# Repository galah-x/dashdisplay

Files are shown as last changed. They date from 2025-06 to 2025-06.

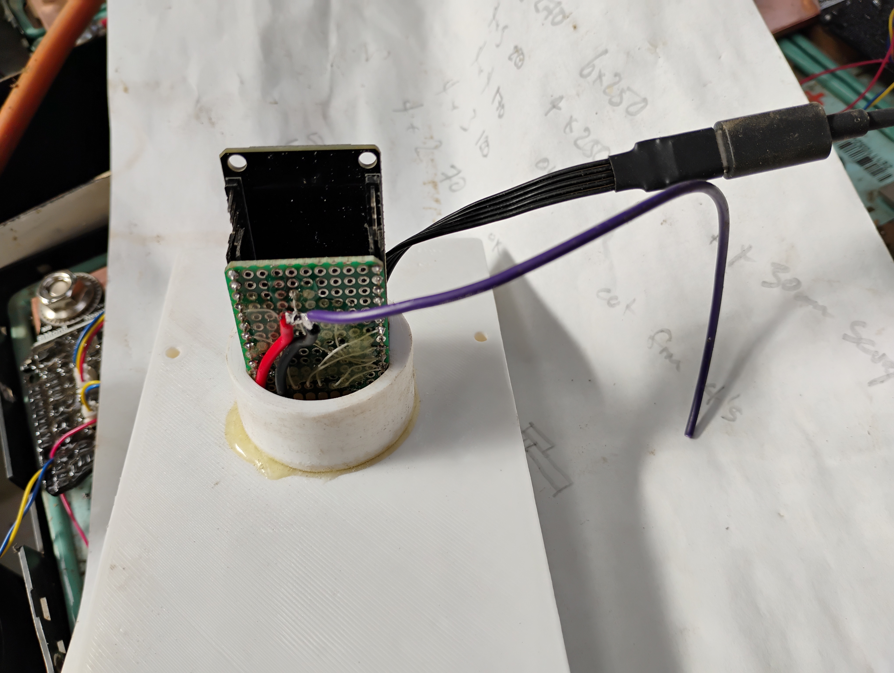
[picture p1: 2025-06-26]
pics/13_assembly_order.jpg

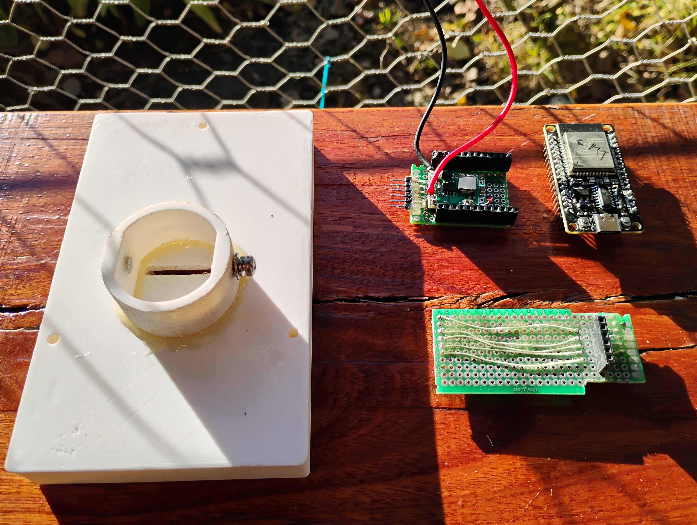
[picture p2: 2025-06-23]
pics/04_components_glued.jpg

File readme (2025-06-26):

Readme for Dashdisplay.
John Sheahan June 2025

This thing is a dashboard display for an Electric Haflinger I'm building. I want to be able to monitor battery voltage, current and StateOfCharge. I also wanted to see the range of individual cell voltages and cell temperatures.

All of this information is available to the BMS, and the Batrium BMS I have thoughtfully broadcasts the relevant information using UDP on its internal wireleass AP. Batrium is even civilized enough to document and publish the detail on their wiki.

So its pretty easy to build a display with an ESP32 and some Sharp sunlight readable sort-of-LCDs from Adafruit to display the desired information on the dashboard with no wiring except 12V power.

The code needs an Arduino setup with ESP32 support loaded.   Its the .h and .ino files. And a few standard add-in libraries the compiler will flag.

Programming the ESP32 board is done with a usb-C cable from the arduino UI.

Use the arduino serial monitor to program your WiFI AP SSID and password. Serial runs at 115200 baud.  I discovered the Batrium SSID with my phone searching for WiFi. The Batrium password is pin123456, replace 123456 with the pinnumber written on the back of the WatchMon.

I wrote a test script test_app/udp_tester.pl you can use to test the dispay if you build one, without actually needing a Batrium setup and/or being close to it.

The dashdisplay has the following hardware components:
  * a 3d printed front frame to hold the 2 LCDs and a wiring board for them.
  * a clear acrylic front plate
  * 2 adafruit sharp lcd displays. 400x240 pixels. Add a 6 pin machine screw pin header to each.
  * a wiring board. I used a scrap of FR4 protoboard with 2 6 pin machine screw socket strips and a 6 pin socket strip on the back. The 2 displays Vin, gnd, spi_clk, spi_mosi are in paralell. The 2 CS pins are brought out separately.
  * the round spigot on the back of the front frame goes through a hole in the dash

Then the is some electronics:
  * a 'motherboard' with socket strip pins to hold an ESP32 module.
  * motherboard has 6 pins of 0.1 inch pinstrip at the front
  * motherboard has a small 12V to 5V switching module on it also, aliexpress
  * motherboard has 10 wires on the back
  * esp32 wroom 32 module from aliexpress.
  * optional flexible right angle USBC cable to alow reprogramming. Mine came from Aliexpress.

Then there is a 3d printed back assembly. It goes over the spigot on the front assembly . The electronics goes inside. There is a spot for a XT60 flanged connector for 12V. And a hole to let the USBC cable out. Probably should silicone up the cable hole once the cable is fitted.

Both 3D printed part needs supports. Cleaning out the support was tedious. They should probably be designed the other way up (a change to the front spigot would be needed).  Feel free to do that better. Freecad design (I used version 1.0.1) stl files and gcode are in the repo. 

There are schematics of the mother and display wiring boards  in teh schematics directory.
There are a few pictures of the bits and the assembly, with the display working against the batrium  WatchMon , in the
pics directory.

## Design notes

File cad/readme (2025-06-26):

Some of the files here, and their issues.:

dd_3.FCStd
Is the original front , with a spigot.
It prints from the outside front face down.
I printed it with supports, so it takes quite a while to clean up.
Its generally too tight on the display in XY and tight on the display wiring board in Z. 
Worked for SW dev.

 - Currently these three parts are used.
 - about 7 hrs to print dd_front_nospigot.FCStd, 1 hr for the spigot, 4 hrs for dd3_back2.FCStd
   - on the mighty Creality ender3v2 that is. In PLA.

dd3_back2.FCStd
This is the original and so far only surround around the esp32. It goes over the spigot.
It prints spigot side down. This needed vigourous sanding with a dremel sandpaper drum to remove supports.
Otherwise it seems OK.
If I needed another one I'd redraw it with a taper around the waist so it prints in reverse (ie solid back on the bed) with no supports. 

dd_front_nospigot.FCStd
This is a redraw of dd_3.FCStd to add 0.5mm all around the display, and an extra mm of Z for both
display and wiring board.  Its designed to print with the rear (surface on dash) on the bed. No supports needed.
No spigot, just a groove to locate the spigot while its epoxied in. 
I also changed to heat formed stakes to hold down the display, which was a mistake. They missed position by a
few tenths of a mm,  and were too fragile to shave down. I just broke them off and will fit either self tappers or maybe a bit of filament to hold the displays in. Self tappers are on order. I pushed in some 2.5mm heat set threaded inserts. As I didn't have holes with walls, was a little ordinary, but worked.
Note I had to ease the slot for the connector in the front.

dd_spigot.FCStd
The same spigot design used in the first one, without the front, and a pointy end to match the groove in dd_front_nospigot.FCStd

Note assembly is a bit tricky. See the pictures.
Glue in the spigot.
Ease the slot for the 0.1 inch pinstrip in the front piece with a file.
Fit the display wiring board.
Fit flexible right angle USB cable to the ESP32. This will allow reprogramming later without disassembly.
fit 12v wires. Leave then long.
Fit motherboard into the connecter for the display board.
Mount front board through dash
feed the USB and 12V leads through the back printed part.
push the back cover on, bringing the leads out.
Solder the 2 12V wires to the XP60 connector, as short as practical.
screw in the xp60
screw in the back
plug in and screw in the 2 displays from the front.

Thats all a bit messy.

Changes I should make:

Front
  * displays should be held in with screws or nutserts, not thermal posts. Also the exact placement of the posts is wrong by a few tenths of a mm.  the posts dont have a hole with walls nder for either nutserts or self tappers.
  * the slot for the female pin strip is too narrow. Display to motherboard connector.  Needs filing currently.

Spigot
  * cheeks for the 4mm nutserts are a bit small. Reduce to 3mm?

Back
  * prints backwards. want to do flat back on the printer bed. Far too much cleanup curently. Maybe a taper to the shoulder.
  * Assembly is difficult. I'd prefer to be able to assemble without removing the XP60. Have to bend the flex USB cable too.
    * Could I add an extra small connector in the 12V so the XP60 plugs in?
      * as I need to plug the MB into display board, then feed wires into the holes in the back, while sliding back over spigot, would be a long wire to locate somewhere.  Right now I use a single feeder wire soldered to both red and black ends to pull through, prior to unsoldering feeder then soldering on XP60. 
    * Could I do a slot so the wires fit between spigot and back?
    * XP60 on the back of the front part? (not nice).
    * perhaps the 12V to 5V switcher should be on a bulge on the side of the back, so that USB is the only cable?
    * or even usb to a separate blob nearly, with 12V on one side and usbC on the other. Unplug the USB for programming. Keep it flat to the display so as to not shroud the wifi antenna of the wsp32 module. 
  * Hopefully doesn't have to come apart often.

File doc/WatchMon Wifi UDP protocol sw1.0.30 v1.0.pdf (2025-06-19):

Watchmon SW 1.0.30 UDP Outbound protocol

## WatchMon - Wifi UDP protocol

Version
1.0 – 1/12/2017 – Software 1.0.30

Communication Overview
Outbound messages are broadcast to
Supervisor broadcasts to udp port 18542 at IP 255.255255.255

Payload format
- | Pos 0 | “:” Start Header character colin (0x3A)
- Pos 1..2 UInt16 MessageType
- | Pos 3 | “,” seperator comma
- Pos 4 uint16 SystemID
- Pos 6 uint16 HubID (default 0 - future extension of SystemID )

Wifi Broadcast modes
- Idle – no broadcast communication
- Limited - Only send Discover MsgType every 1.5 Seconds
- Verbose (default) - All messages scheduled in their relevate frequency slot transmitted at ~50mS interval
- Verbose (read only)
- Disabled - module powered down

## Outbound messages Types

Frequency A - 150 millisecond
- 0x415A – Individual cell monitor Basic Status (subset for up to 16)
- 0x4232 – Individual cell monitor Full Info (node specific)

Frequency B - 300 milliseconds
- 0X3E32 – Telemetry - Combined Status Rapid Info

Frequency C - 1.5 seconds
- 0X3F33 – Telemetry - Combined Status Fast Info
- 0X4732 – Telemetry - Logic Control Status Info
- 0x4932 – Telemetry - Remote Status Info
- 0x6131 – Telemetry - Communication Status Info
- 0x5732 – System Discovery Info

Frequency D - 22 seconds
- 0X4032 – Telemetry - Combined Status Slow Info
- 0x5432 – Telemetry - Daily Session Info
- 0x7857 – Telemetry - Shunt Metric Info
- 0x5632 – Telemetry - Life Metric Info
- 0X4A35 – Hardware - System setup configuration Info
- 0X4B35 – Hardware - Cell Group setup configuration Info
- 0X4C33 – Hardware - Shunt setup configuration Info
- 0X4D33 – Hardware - Expansion setup configuration Info
- 0X5334 – Hardware - Integration setup configuration Info
- 0X4F33 – Control logic – Critical setup configuration Info
- 0X5033 – Control logic - Charge setup configuration Info
- 0X5158 – Control logic - Discharge setup configuration Info
- 0X5258 – Control logic - Thermal setup configuration Info
- 0X4E58 – Control logic - Remote setup configuration Info

Frequency E - Adhoc request / response
- 0x5831 – Telemetry - Daily Session History
- 0x6831 – Telemetry - Quick Session History
- 0x5431 – Telemetry - Session Metrics

## System Discovery Information – payload formatting

Identifier: 0X5732 Recommended to monitor
Frequency: 1.55 seconds
Data Length: 50 bytes
Version 2
Field | Offset | Data Type | Format / Range | Resolution / Notes
System Code | 8 | Text 8
Firmware Version | 16 | Uint16
Hardware Version | 18 | Uint16
Device Time | 20 | Uint32 | Unix Epoch | seconds since 1-1-1970
System Op status | 24 | Uint8 | Timeout = 0, Idle = 1, // LED = green slow pulse Charging = 2, // LED = blue slow pulse Discharging = 3, // LED = green solid Full = 4, // LED = blue double blink Empty = 5, // LED = green double blink Simulator = 6 , // LED = rainbow pulse CriticalPending = 7, // LED = red fast pulse CriticalOffline = 8, // LED = red slow pulse MqttOffline = 9, // LED = white blink AuthSetup = 10, // LED = white solid
System Auth Mode | 25 | Uint8 | 0 = Default 1 = Technician 2 = Factory
Critical BattOkState | 26 | Bool | 0 or 1
Charge PowerRate State | 27 | Uint8 | Off = 0, Limited = 2, Normal = 4,
Discharge PowerRate State | 28 | Uint8
Heat On State | 29 | Bool | 0 or 1
Cool On State | 30 | Bool | 0 or 1
Min Cell Volt | 31 | Uint16 | 0 to 6,500 mV | 1mV / bit and nil offset
Max Cell Volt | 33 | Uint16 | 0 to 6,500 mV | 1mV / bit and nil offset
Avg Cell Volt | 35 | Uint16 | 0 to 6,500 mV | 1mV / bit and nil offset
Min Cell Temp | 37 | Uint8 | -40ºC to 125ºC | 1ºC/bit and 40ºC offset
Num of active Cellmons | 38 | Uint8 | 0 to 254
CMU Port Rx USN | 39 | Uint8
CMU Poller Mode | 40 | Uint8 | Idle = 0, Normal = 1, Start collection = 2, Collection running = 3, Start syncronisation = 4, Sync Running = 5, Start NetworkTest = 6, NetworkTest running = 9, Start BypassTest = 7, BypassTest running = 8, Start Reboot All = 10, Reboot All devices = 11, Start Simulator = 12, Simulator running = 13, Undefined = 255,

Cont../

Shunt SoC | 41 | uint8 | -5% to +105% | 0.5% / bit and 5% offset
Shunt Voltage | 42 | Uint16 | | Multiple (100) according to setup
Shunt Current | 44 | Float | mA | (+ charge , - discharge)
Shunt Status | 48 | Uint8 | Timeout = 0, Discharging = 1, Idle = 2, Charging = 4
Shunt RX ticks | 49 | Uint8

## Telemetry - Combined Status Rapid Info – payload formatting

Identifier: 0x3E32 – Recommended to monitor
Frequency: 294 milliseconds
Data Length: 50 bytes
Version 2
Field | Offset | Data Type | Format / Range | Resolution / Notes
Min Cell Voltage | 8 | Uint16 | 0 to 6,500 mV | 1mV / bit and nil offset
Max Cell Voltage | 10 | Uint16 | 0 to 6,500 mV | 1mV / bit and nil offset
Min Cell Volt Reference | 12 | Uint8 | 0 to 250 | Node Identifier
Max Cell Volt Reference | 13 | Uint8 | 0 to 250 | Node Identifier
Min Cell Temperature | 14 | uint8 | -40ºC to 125ºC | 1ºC/bit and 40ºC offset
Min Cell Temperature | 15 | uint8 | -40ºC to 125ºC | 1ºC/bit and 40ºC offset
Min Cell Temp Reference | 16 | Uint8 | 0 to 250 | Node Identifier
Max Cell Temp Reference | 17 | Uint8 | 0 to 250 | Node Identifier
Min Cell Bypass Current | 18 | Uint16 | 0 to 2,500 mA | 1mA / bit and nil offset
Max Cell Bypass Current | 20 | Uint16 | 0 to 2,500 mA | 1mA / bit and nil offset
Min Cell Bypass Ref ID | 22 | Uint8 | 0 to 250 | Node Identifier
Max Cell Bypass Ref ID | 23 | Uint8 | 0 to 250 | Node Identifier
Min Bypass Temperature | 24 | uint8 | -40ºC to 125ºC | 1ºC/bit and 40ºC offset
Min Bypass Temperature | 25 | uint8 | -40ºC to 125ºC | 1ºC/bit and 40ºC offset
Min Bypass Temp Ref ID | 26 | Uint8 | 0 to 250 | Node Identifier
Max Bypass Temp Ref ID | 27 | Uint8 | 0 to 250 | Node Identifier
Average Cell Voltage | 28 | Uint16 | 0 to 6,500 mV | 1mV / bit and nil offset
Average Cell Temperature | 30 | uint8 | -40ºC to 125ºC | 1ºC/bit and 40ºC offset
Num# of Cells Above Initial Bypass | 31 | Uint8 | 0 to 250
Num# of Cells Above Final Bypass | 32 | Uint8 | 0 to 250
Num# of Cells in Bypass | 33 | Uint8 | 0 to 250
Num# of Cells Overdue | 34 | Uint8 | 0 to 250
Num# of Cells Active | 35 | Uint8 | 0 to 250
Num# of Cells in System | 36 | Uint8 | 0 to 250
CMU port TX NodeID | 37 | Uint8
CMU port RX NodeID | 38 | Uint8
CMU port RX USN | 39 | Uint8 | 0 to 254 | Serial number packet counter
Shunt Voltage | 40 | Uint16 | | Multiple (100) according to setup
Shunt Amp | 42 | Float | mA | (+ charge , - discharge)
Shunt Power | 46 | Float | VA | (+ charge , - discharge)

## Telemetry - Combined Status Fast Info – payload formatting

Identifier: 0X3F33 – Recommended to monitor
Frequency: 1.55 seconds
Version: 3
Data Length: 80 bytes
Field | Offset | Data Type | Format / Range | Resolution / Notes
CMU Poller Mode | 8 | Uint8 | 0 = Idle, 1 = Normal, 2 = Start collection, 3= Collection running, 4 = Start synchronisation, 5 = Sync Running, 6 = Start NetworkTest, 9 = NetworkTest running, 7 = Start BypassTest, 8 = BypassTest running, 10 = Start Reboot All, 11 = Reboot All devices, 12 = Start Simulator, 13 = Simulator running,
CMU Port TX Ack count | 9 | Uint8 | 0 to 250
CMU Port TX Op Status NodeID | 10 | Uint8 | | Node Identifier
CMU Port TX Op Status USN | 11 | Uint8 | 0 to 254 | Serial packet counter
CMU Port TX Op Parameter NodeID | 12 | uint8 | | Node Identifier
Group Min Cell Volt | 13 | Uint16 | 0 to 6,500 mV | 1mV / bit and nil offset
Group Max Cell Volt | 15 | Uint16 | 0 to 6,500 mV | 1mV / bit and nil offset
Group Min Cell Temp | 17 | Uint8 | -40ºC to 125ºC | 1ºC/bit and 40ºC offset
Group Max Cell Temp | 18 | Uint8 | -40ºC to 125ºC | 1ºC/bit and 40ºC offset
CMU Port RX Op Status NodeID | 19 | Uint8 | 0 to 250 | Node Identifier
CMU Port RX Op Status Group Acknowledgement | 20 | Uint8
CMU Port RX Op Status USN | 21 | Uint8 | 0 to 254 | Serial packet counter
CMU Port RX Op Parameter NodeID | 22 | Uint8 | 0 to 250 | Node Identifier
System Op status | 23 | Uint8 | Timeout = 0, Idle = 1, // LED = green slow pulse Charging = 2, // LED = blue slow pulse Discharging = 3, // LED = green solid Full = 4, // LED = blue double blink Empty = 5, // LED = green double blink Simulator = 6 , // LED = rainbow pulse CriticalPending = 7, // LED = red fast pulse CriticalOffline = 8, // LED = red slow pulse MqttOffline = 9, // LED = white blink AuthSetup = 10, // LED = white solid
System Auth Mode | 24 | Uint8 | 0 = Default 1 = Technician 2 = Factory
System Supply Volt | 25 | Uint16 | 0 to 6,500 mV | 1mV / bit and nil offset
System Ambient Temp | 27 | Uint8 | -40ºC to 125ºC | 1ºC/bit and 40ºC offset
System Device Time | 28 | Uint32 | Date Time | 1sec/bit since 1.1.1970
Shunt State of Charge | 32 | Uint8 | -5% to +105% | 0.5% / bit and 5% offset

Shunt Celsius | 33 | Uint8 | -40ºC to 125ºC | 1ºC/bit and 40ºC offset
Shunt Nom. Capacity to full | 34 | Float | mAh
Shunt Nom. Capacity to empty | 38 | Float | mAh
Shunt Poller Mode | 42 | Uint8 | 0 = Start sync, 1 = Sync running, 2 = Normal, 3 = Idle,
Shunt Status | 43 | Uint8 | Timeout = 0, Discharging = 1, Idle = 2, Charging = 4
Shunt Lo State of Charge Re Calibration | 44 | Bool | 0 or 1
Shunt Hi State of Charge Re Calibration | 45 | Bool | 0 or 1
Expansion Output Battery On | 46 | Bool | 0 or 1
Expansion Output Battery Off | 47 | Bool | 0 or 1
Expansion Output Load On | 48 | Bool | 0 or 1
Expansion Output Load Off | 49 | Bool | 0 or 1
Expansion Output Relay 1 | 50 | Bool | 0 or 1
Expansion Output Relay 2 | 51 | Bool | 0 or 1
Expansion Output Relay 3 | 52 | Bool | 0 or 1
Expansion Output Relay 4 | 53 | Bool | 0 or 1
Expansion Output PWM1 | 54 | Uint16
Expansion Output PWM2 | 56 | Uint16
Expansion Input Run LED Mode | 58 | Bool | 0 or 1
Expansion Input Charge Normal Mode | 59 | Bool | 0 or 1
Expansion Input Battery Contactor | 60 | Bool | 0 or 1
Expansion Input Load Contactor | 61 | Bool | 0 or 1
Expansion Input Signal In | 62 | Uint8
Expansion Input AIN1 | 63 | Uint16
Expansion Input AIN2 | 65 | Uint16
Min Bypass Session | 67 | Float | mAh | mAh
Max Bypass Session | 71 | Float | mAh | mAh
Min Bypass Session Reference | 75 | Uint8 | 0 to 250 | Node Identifier for Min
Max Bypass Session Reference | 76 | Uint8 | 0 to 250 | Node Identifier for Max
Rebalance Bypass extra | 77 | Bool | 0 or 1 | When invoked
Repeat Cell Volt Counter | 78 | Uint16 | 0 to 6700 | Num of msg with cell voltage unchanged

## Telemetry - Combined Status Slow Information – payload formatting

Identifier: 0X4032
Frequency: 22 seconds
Data Length: 66 bytes
Version: 2
Field | Offset | Data Type | Format / Range | Resolution / Notes
Sys Start up Time | 8 | Uint32 | Unix Epoch | seconds since 1-1-1970
Sys Process Control | 12 | Bool | 0 or 1
Sys Is Initial Start up | 13 | Bool | 0 or 1
Sys Ignore When Cells Overdue | 14 | Bool | 0 or 1
Sys Ignore When Shunts Overdue | 15 | Bool | 0 or 1
Monitor Daily Session Stats for system | 16 | Bool | 0 or 1
Setup Version for System | 17 | Uint8 | 0 to 255 | Incremental version number when saved to track when updates made
Setup Version for Cell Group | 18 | Uint8 | 0 to 255 | Incremental version number when saved to track when updates made
Setup Version for Shunt | 19 | Uint8 | 0 to 255 | Incremental version number when saved to track when updates made
Setup Version for Expansion | 20 | Uint8 | 0 to 255 | Incremental version number when saved to track when updates made
Setup Version for Comms Channel | 21 | Uint8 | 0 to 255 | Incremental version number when saved to track when updates made
Setup Version for Critical | 22 | Uint8 | 0 to 255 | Incremental version number when saved to track when updates made
Setup Version for Charge | 23 | Uint8 | 0 to 255 | Incremental version number when saved to track when updates made
Setup Version for Discharge | 24 | Uint8 | 0 to 255 | Incremental version number when saved to track when updates made
Setup Version for Thermal | 25 | Uint8 | 0 to 255 | Incremental version number when saved to track when updates made
Setup Version for Remote | 26 | Uint8 | 0 to 255 | Incremental version number when saved to track when updates made
Setup Version for Scheduler | 27 | Uint8 | 0 to 255 | Incremental version number when saved to track when updates made
Shunt Estimated Duration To Full in mins | 28 | Uint16 | | 1 minute / bit and nil offset
Shunt Estimated Duration To Empty in mins | 30 | Uint16 | | 1 minute / bit and nil offset
Shunt Recent Charge mAh Average | 32 | Float | mAh
Shunt Recent Discharge mAh Average | 36 | Float | mAh
Shunt Recent Nett mAh | 40 | Float | mAh
Has Shunt SoC Count Lo | 44 | Bool | 0 or 1
Has Shunt SoC Count Hi | 45 | Bool | 0 or 1
Quick Session Recent Time | 46 | Uint32 | Unix Epoch | seconds since 1-1-1970
Quick Session Number of Records | 50 | Uint16
Quick Session Max Records | 52 | Uint16
Shunt Nett Accumulated Count | 54 | Int64
Shunt Nominal Capacity to Empty | 62 | Float | mAh

## Telemetry - Logic Control Status Information – payload formatting

Identifier: 0X4732
Frequency: 1.55 seconds
Data Length: 79 bytes
Version 2
Field | Offset | Data Type | Format / Range | Resolution / Notes
Critical is Battery OK – current State | 8 | Bool | 0 or 1
Critical Is Battery OK – live calc | 9 | Bool | 0 or 1
Critical Is Transition | 10 | Bool | 0 or 1
Critical Has Cells Overdue | 11 | Bool | 0 or 1
Critical Has Cells in Low Voltage State | 12 | Bool | 0 or 1
Critical Has Cells in High Voltage State | 13 | Bool | 0 or 1
Critical Has Cells in Low Temp | 14 | Bool | 0 or 1
Critical has Cells in high Temp | 15 | Bool | 0 or 1
Critical Has Supply Voltage Low | 16 | Bool | 0 or 1
Critical Has Supply Voltage High | 17 | Bool | 0 or 1
Critical Has Ambient Temp Low | 18 | Bool | 0 or 1
Critical Has Ambient Temp High | 19 | Bool | 0 or 1
Critical Has Shunt Voltage Low | 20 | Bool | 0 or 1
Critical Has Shunt Voltage High | 21 | Bool | 0 or 1
Critical Has Shunt Low Idle Volt | 22 | Bool | 0 or 1
Critical Has Shunt Peak Charge | 23 | Bool | 0 or 1
Critical Has Shunt Peak Discharge | 24 | Bool | 0 or 1
Charging Is ON State | 25 | Bool | 0 or 1
Charging is Limited Power | 26 | Bool | 0 or 1
Charging is in Transition | 27 | Bool | 0 or 1
Charging Power Rate – current state | 28 | Uint8 | 0 = Off, 2 = Limited power, 4 = Normal power,
Charging Power Rate - live calc | 29 | Uint8 | 0 = Off, 2 = Limited power, 4 = Normal power,
Charging Has Cell Volt High | 30 | Bool | 0 or 1
Charging Has Cell Volt Pause | 31 | Bool | 0 or 1
Charging Has Cell Volt Limited Power | 32 | Bool | 0 or 1
Charging Has Cell Temp Low | 33 | Bool | 0 or 1
Charging Has Cell Temp High | 34 | Bool | 0 or 1
Charging Has Ambient Temp Low | 35 | Bool | 0 or 1
Charging Has Ambient Temp High | 36 | Bool | 0 or 1
Charging Has Supply Volt High | 37 | Bool | 0 or 1
Charging Has Supply Volt Pause | 38 | Bool | 0 or 1
Charging Has Shunt Volt High | 39 | Bool | 0 or 1
Charging Has Shunt Volt Pause | 40 | Bool | 0 or 1
Charging Has Shunt Volt Lim Power | 41 | Bool | 0 or 1
Charging Has Shunt Soc High | 42 | Bool | 0 or 1
Charging Has Shunt Soc Pause | 43 | Bool | 0 or 1
Charging Has Cells Above Initial Bypass | 44 | Bool | 0 or 1
Charging Has Cells Above Final Bypass | 45 | Bool | 0 or 1
Charging Has Cells In Bypass | 46 | Bool | 0 or 1
Charging Has Bypass Complete | 47 | Bool | 0 or 1
Charging Has Bypass Temp Relief | 48 | Bool | 0 or 1
Discharging Is ON State | 49 | Bool | 0 or 1
Discharging is Limited Power | 50 | Bool | 0 or 1
Discharging is in Transition | 51 | Bool | 0 or 1
Discharging Power Rate – current state | 52 | Uint8 | 0 = Off, 2 = Limited power,

| | | 4 = Normal power,
Discharging Power Rate – live calc | 53 | Uint8 | 0 = Off, 2 = Limited power, 4 = Normal power,
Discharging Has Cell Volt Low | 54 | Bool | 0 or 1
Discharging Has Cell Volt Pause | 55 | Bool | 0 or 1
Discharging Has Cell Volt Limited Power | 56 | Bool | 0 or 1
Discharging Has Cell Temp Low | 57 | Bool | 0 or 1
Discharging Has Cell Temp High | 58 | Bool | 0 or 1
Discharging Has Ambient Temp Low | 59 | Bool | 0 or 1
Discharging Has Ambient Temp High | 60 | Bool | 0 or 1
Discharging Has Supply Volt Low | 61 | Bool | 0 or 1
Discharging Has Supply Volt Pause | 62 | Bool | 0 or 1
Discharging Has Shunt Volt Low | 63 | Bool | 0 or 1
Discharging Has Shunt Volt Pause | 64 | Bool | 0 or 1
Discharging Has Shunt Volt Limited Power | 65 | Bool | 0 or 1
Discharging Has Shunt Soc Low | 66 | Bool | 0 or 1
Discharging Has Shunt Soc Pause | 67 | Bool | 0 or 1
Thermal Heat ON – current state | 68 | Bool | 0 or 1
Thermal Heat ON – live calc | 69 | Bool | 0 or 1
Thermal Transition Heat ON | 70 | Bool | 0 or 1
Thermal Ambient Temp Low | 71 | Bool | 0 or 1
Thermal Cells In Temp Low | 72 | Bool | 0 or 1
Thermal Cool ON – current state | 73 | Bool | 0 or 1
Thermal Cool ON – live calc | 74 | Bool | 0 or 1
Thermal Transition Cool ON | 75 | Bool | 0 or 1
Thermal Ambient Temp High | 76 | Bool | 0 or 1
Thermal Cells In Temp High | 77 | Bool | 0 or 1
Charging Has Bypass Session Low | 78 | Bool | 0 or 1

## Telemetry - Remote Status Information – payload formatting

Identifier: 0X4932
Frequency: 1.55 seconds
Data Length: 62 bytes
Version: 2
Field | Offset | Data Type | Format / Range | Resolution / Notes
Canbus RX ticks | 8 | Uint8 | 0 to 254
Canbus RX unknown ticks | 9 | Uint8 | 0 to 254
Canbus TX ticks | 10 | Uint8 | 0 to 254
Charge Actual Celsius | 11 | Uint8 | | User-defined
Charge Target Volt | 12 | Uint16 | 0 to 650.00 V | User-defined (i.e. 10mV / bit, 5400 = 54.00V)
Charge Target Amp | 14 | Uint16 | 0 to 650.00 A | User-defined (i.e. 10mA / bit, 12000 = 120.0A)
Charge Target VA | 16 | Uint16 | 0 to 65,000 | User-defined (i.e. 1VA / bit, 5000 = 5.00kVA)
Charge Actual Volt | 18 | Uint16 | 0 to 650.00 V | User-defined (i.e. 10mV / bit, 5400 = 54.00V)
Charge Actual Amp | 20 | Uint16 | 0 to 650.00 A | User-defined (i.e. 10mA / bit, 12000 = 120.0A)
Charge Actual VA | 22 | Uint16 | 0 to 65,000 | User-defined (i.e. 1VA / bit, 5000 = 5.00kVA)
Charge Actual Flags 1 | 24 | Uint32 | | User-defined
Charge Actual Flags 2 | 28 | Uint32 | | User-defined
Charge Actual Rx Time | 32 | Uint32 | Unix Epoch | seconds since 1-1-1970
reserved | 36
Discharge Actual Celsius | 37 | Uint8 | | User-defined
Discharge Target Volt | 38 | Uint16 | 0 to 650.00 V | User-defined (i.e. 10mV / bit, 5400 = 54.00V)
Discharge Target Amp | 40 | Uint16 | 0 to 650.00 A | User-defined (i.e. 10mA / bit, 12000 = 120.0A)
Discharge Target VA | 42 | Uint16 | 0 to 65,000 | User-defined (i.e. 1VA / bit, 5000 = 5.00kVA)
Discharge Actual Volt | 44 | Uint16 | 0 to 650.00 V | User-defined (i.e. 10mV / bit, 5400 = 54.00V)
Discharge Actual Amp | 46 | Uint16 | 0 to 650.00 A | User-defined (i.e. 10mA / bit, 12000 = 120.0A)
Discharge Actual VA | 48 | Uint16 | 0 to 65,000 | User-defined (i.e. 1VA / bit, 5000 = 5.00kVA)
Discharge Actual Flags 1 | 50 | Uint32 | | User-defined
Discharge Actual Flags 2 | 54 | Uint32 | | User-defined
Discharge Actual Rx Time | 58 | Uint32 | Unix Epoch | seconds since 1-1-1970

## Telemetry - Status Comms Info – payload formatting

Identifier: 0X6131
Frequency: 1.55 seconds
Data Length: 33 bytes
Version: 1
Field | Offse t | Data Type | Format / Range | Resolution / Notes
Device Time | 8 | Uint32 | Unix Epoch | seconds since 1-1-1970
System Op status | 12 | Uint8 | Timeout = 0, Idle = 1, // LED = green slow pulse Charging = 2, // LED = blue slow pulse Discharging = 3, // LED = green solid Full = 4, // LED = blue double blink Empty = 5, // LED = green double blink Simulator = 6 , // LED = rainbow pulse Critical Pending = 7, // LED = red fast pulse Critical Offline = 8, // LED = red slow pulse Mqtt Offline = 9, // LED = white blink Auth Setup = 10, // LED = white solid
System Auth Mode | 13 | Uint8 | 0 = Default 1 = Technician 2 = Factory
Auth Token | 14 | Uint16
Auth Rejection Attempts | 16 | Uint8 | 0 to 254
Wifi State | 17 | Uint8 | Broadcast Start = 0, Broadcast Prep = 1, Broadcast TxSetup = 2, Broadcast Running = 3, UsbCmd Start = 4, UsbCmd Running = 5, UsbCmd PassThru = 6, UsbProg Start = 7, UsbProg Running = 8, UsbProg PassThru = 9, Offline Start = 10, Offline Running = 11, Offline Stop = 12, Limited Start = 13, Limited Prep = 14, Limited Running = 15, JoinAp Start = 16, JoinAp Running = 17,
Wifi Tx Cmd Ticks | 18 | Uint8 | 0 to 250
Wifi Rx Cmd Ticks | 19 | Uint8 | 0 to 250
Wifi Rx Unknown Ticks | 20 | Uint8 | 0 to 250

Continue../

Canbus Status | 21 | Uint8 | | Reserved
Canbus Rx Cmd Ticks | 22 | Uint8 | 0 to 250
Canbus Rx Unknown Ticks | 23 | Uint8 | 0 to 250
Canbus Tx Cmd Ticks | 24 | Uint8 | 0 to 250
Shunt Poller Mode | 25 | Uint8 | 0 = Start sync, 1 = Sync running, 2 = Normal, 3 = Idle,
Shunt Status | 26 | Uint8 | Timeout = 0, Discharging = 1, Idle = 2, Charging = 4
Shunt Tx Ticks | 27 | Uint8 | 0 to 250
Shunt Rx Ticks | 28 | Uint8 | 0 to 250
CMU Poller Mode | 29 | | 0 = Idle, 1 = Normal, 2 = Start collection, 3= Collection running, 4 = Start synchronisation, 5 = Sync Running, 6 = Start NetworkTest, 9 = NetworkTest running, 7 = Start BypassTest, 8 = BypassTest running, 10 = Start Reboot All, 11 = Reboot All devices, 12 = Start Simulator, 13 = Simulator running,
Cellmon CMU Status | 30 | | | Reserved
Cellmon CMU Tx USN | 31 | Uint8 | 0 to 250 | Will be switched to ticks
Cellmon CMU Rx USN | 32 | Uint8 | 0 to 250 | Will be switched to ticks

## Hardware - System Setup configuration info – payload formatting

Identifier: 0X4A35
Frequency: 22 seconds
Data Length: 76 bytes
Version: 5
Field | Offset | Data Type | Format / Range | Resolution / Notes
Setup Version | 8 | Uint8 | 0 to 255 | Incremental version number when saved to track when updates made
System Code | 10 | Text 8
System Name | 18 | Text 20
Asset Code | 38 | Text 20
Allow Tech Authority | 58 | Bool | 0 or 1
Allow QuickSession | 59 | Bool | 0 or 1
Quick Session lntervall | 60 | Uint32 | milliSeconds | 30s,60s,2min or 5min
Preset ID | 64 | Uint16 | | #1
Firmware Version | 66 | Uint16 | | #1
Hardware Version | 68 | Uint16 | | #1
Serial Number | 70 | Uint32 | | #1
Show Scheduler | 74 | Bool | 0 or 1
Show StripCycle | 75 | Bool | 0 or 1
#1 has been included for information only

## Hardware - Cell Group Setup configuration info – payload formatting

Identifier: 0X4B35
Frequency: 22 seconds
Data Length: 53 bytes
Version: 5
Field | Offset | Data Type | Format / Range | Resolution / Notes
Setup Version | 8 | Uint8 | 0 to 255 | Incremental version number when saved to track when updates made
Battery Type ID | 9 | Uint8 | 0 = Custom, 1 = Li-FePO4 Typical 4 = Li-FePO4 Long Life, 2 = Li-Ion Performance 3 = Li-Ion Long Life
First Node ID | 10 | Uint8 | | Node Identifier
Last Node ID | 11 | Uint8 | | Node Identifier
Nominal Cell Voltage | 12 | Uint16 | 0 to 6,500 mV | 1mV / bit and nil offset
Low Cell Voltage | 14 | Uint16 | 0 to 6,500 mV | 1mV / bit and nil offset
High Cell Voltage | 16 | Uint16 | 0 to 6,500 mV | 1mV / bit and nil offset
Bypass Voltage Level | 18 | Uint16 | 0 to 6,500 mV | 1mV / bit and nil offset
Bypass Amp Limit | 20 | Uint16 | 0 to 2,500 mA | 1mA / bit and nil offset
Bypass Temp Limit | 22 | Uint8 | -40ºC to 125ºC | 1ºC/bit and 40ºC offset
Low Cell Temp | 23 | Uint8 | -40ºC to 125ºC | 1ºC/bit and 40ºC offset
High Cell Temp | 24 | Uint8 | -40ºC to 125ºC | 1ºC/bit and 40ºC offset
Diff Nom Cells in Series | 25 | Bool | 0 or 1
Nom Cells in Series | 26 | Uint8
Allow Entire Range | 27 | Bool | 0 or 1
First Node ID of Entire Range | 28 | Uint8 | | Node Identifier
Last Node ID of Entire Range | 29 | Uint8 | | Node Identifier
Bypass Extra Mode | 30 | Uint8 | 0 = None, 1 = Idle Shunt 2 =Same cell volt, 3 = Auto Level
Bypass Latch Interval | 31 | Uint16 | | 1mS/bit
CellMon Type ID | 33 | Uint8 | 0 = Custom, 1 = GenMon2W, 2 = GenMon8W, 3 = LongMon, 4 = BlockMonM8, 5 = BlockMonM14 6 = EndMon, 7 = ManyMon,
Bypass Impedance | 34 | Float
Bypass CellVolt low cutout | 38 | Uint16 | 0 to 6,500 mV | 1mV / bit and nil offset
Bypass Shunt Amp Limit – Charge | 40 | Uint16 | 0 to 6,500 mA | 1mA / bit and nil offset
Bypass Shunt Amp Limit – Discharge | 42 | Uint16 | 0 to 6,500 mA | 1mA / bit and nil offset
Bypass Shunt SoC% Min Limit | 44 | Uint8 | -5% to +105% | 0.5% / bit and 5% offset
Bypass Cell Volt Banding | 45 | Uint16 | 0 to 6,500 mV | 1mV / bit and nil offset
Bypass Cell Volt Difference | 47 | Uint16 | 0 to 6,500 mV | 1mV / bit and nil offset
Bypass Stable Interval | 49 | Uint16
Bypass Extra Amp Limit | 51 | Uint16 | 0 to 2,500 mA | 1mA / bit and nil offset

## Hardware - Shunt setup configuration info – payload formatting

Identifier: 0X4C33
Frequency: 22 seconds
Data Length: 60 bytes
Version: 3
Field | Offset | Data Type | Format / Range | Resolution / Notes
Shunt Type ID | 8 | Uint8 | 0 = None, 1 = SFP102MOD 100uOhm 375A 150V 2 = SFP101EVB 72uOhm 500A 150V 3 = SFP101EVB 25uOhm 1500A 150V 4 = SFP102MOD (4k) 375A 750V 5 = SFP102MOD (3k) 375A 600V 6 = SFP102MOD 100uOhm 375A 150V Negative 7 = SFP102MOD 50uOhm 750A 150V 16 = ShuntMon2 50uOhm 500A 650V 254 = Simulator 255 = Custom
Voltage Scale | 9 | Uint16
Amp Scale | 11 | Uint16
Charge Idle | 13 | Uint16
Discharge Idle | 15 | Uint16
SoC Count Low | 17 | uint8 | -5% to +105% | 0.5% / bit and 5% offset
SoC Count High | 18 | uint8 | -5% to +105% | 0.5% / bit and 5% offset
SoC Lo Recalibration | 19 | uint8 | -5% to +105% | 0.5% / bit and 5% offset
SoC Hi Recalibration | 20 | uint8 | -5% to +105% | 0.5% / bit and 5% offset
Monitor SoC Low Recalibration | 21 | Bool | 0 or 1
Monitor SoC High Recalibration | 22 | Bool | 0 or 1
Monitor in Bypass Recalibration | 23 | Bool | 0 or 1
Nominal Capacity in mAh | 24 | Float
Granularity in Volts | 28 | Float
Granularity in Amps | 32 | Float
Granularity in mAh | 36 | Float
Granularity in Celcius | 40 | Float
Reverse Flow | 44 | Bool | 0 or 1
Setup Version | 45 | Uint8 | 0 to 255 | Incremental version number when saved to track when updates made
Granularity in VA | 46 | Float | | Power
Granularity in VA hour | 50 | Float | | Energy consumed
Max Voltage | 54 | Uint16 | | Device limit for uint16
Max Amp Charge | 56 | Uint16 | | Device limit for uint16
Max Amp Dischg | 58 | Uint16 | | Device limit for uint16

## Hardware - Expansion setup configuration info – payload formatting

Identifier: 0X4D33
Frequency: 22 seconds
Data Length: 32 bytes
Version 3
Field | Offset | Data Type | Format / Range | Resolution / Notes
Setup Version | 8 | Uint8 | 0 to 255 | Incremental version number when saved to track when updates made
Extension Template | 9 | Uint8 | 0 = None 1 = 12v Expansion Board R1 2 = 48v Expansion Board R1 3 = Watchmon CMC 2.0 255 = Custom
Neo Pixel Ext Status Mode | 10 | Uint8 | 0 = None = 0, 1 = Repeat = 1, 2 = 8 segment SoC% 3 = 8 Segment Solid Soc%
Relay 1 function | 11 | Uint8 | 0 = None = 0, 1 = Manual On 2 = Critical Batt Ok 3 = Warning Alert On // obsolete 4 = Charging On 5 = Discharging On 6 = Heating Required 7 = Cooling Required 8 = Run / Idle input 9 = Charge / Normal input 10 = Bypass Complete 11 = Charging Limited 12 = Discharge Limited 13 = Critical Recovery 14 = Critical Pulse On 15 = Critical Pulse Off 16 = Critical Fault 17 = Precharge timer 18 = Fluid pump required 19 = Strip cycle discharge 20 = Strip cycle isolate 21 = warning HVA high volt alert charge 22 = warning LVA low volt alert discharge
Relay 2 function | 12 | Uint8
Relay 3 function | 13 | Uint8
Relay 4 function | 14 | Uint8
Output 5 function | 15 | Uint8
Output 6 function | 16 | Uint8
Output 7 function | 17 | Uint8
Output 8 function | 18 | Uint8
Output 9 function | 19 | Uint8 | Reserved PWM
Output 10 function | 20 | Uint8 | Reserved PWM
Input 1 function | 21 | Uint8 | 0 = None 1 = Run / Idle discharge/critical mode 2 = Critical contact sensor – On 3 = Critical contact sensor - Fault
Input 2 function | 22 | Uint8
Input 3 function | 23 | Uint8
Input 4 function | 24 | Uint8
Input 5 function | 25 | Uint8
Input AIN 1 function | 26 | Uint8
Input AIN 2 function | 27 | Uint8
Custom Feature 1 | 28 | Uint16
Custom Feature 2 | 30 | Uint16

## Hardware - Integration Setup configuration info – payload formatting

Identifier: 0X5334
Frequency: 22 seconds
Data Length: 26 bytes
Version: 4
Field | Offset | Data Type | Format / Range | Resolution / Notes
Setup Version | 8 | Uint8 | 0 to 255 | Incremental version number when saved to track when updates made
USB TX Broadcast | 9 | Bool | 0 or 1
Wifi UDP TX Broadcast | 10 | Bool | 0 or 1
Wifi Broadcast Mode | 11 | Uint8 | 0 = None, 1 = Verbose, 2 = Limited, 3 = Disabled 4 = Readonly Verbose
Canbus TX Broadcast | 11 | Bool | 0 or 1
Canbus Mode | 12 | Uint8 | 0 = None, 1 = Native, 2 = Elcon / TC-charger 3 = En-Power 500k charger 4 = Solax power SK 5 = Sma Sunny Island v3.1 6 = Brusa NLG5 charger 7 = En-Power 250k charger 8 = Solax power SK limited 9 = Brusa NLG6 charger 10 = Project Lychee 11 = Eltek FlatPack2 HE2000/48 14 = Project Thomas 15 = Victron colour control GX 42 = Project42
Canbus Remote Address | 13 | Uint32
Canbus Base Address | 13 | Uint32
Canbus Group Address | 13 | Uint32

## Control Logic - Critical Setup configuration info – payload formatting

Identifier: 0X4F33
Frequency: 22 seconds
Data Length: 75 bytes
Version: 3
Field | Offset | Data Type | Format / Range | Resolution / Notes
Control Mode | 8 | Uint8 | 0 = Auto 1 = Manual ON 2 = Manual OFF
Auto Recovery | 9 | Bool | 0 or 1
Ignore Overdue Cells | 10 | Bool | 0 or 1
Monitor Low Cell Voltage | 11 | Bool | 0 or 1
Monitor High Cell Voltage | 12 | Bool | 0 or 1
Low Cell Voltage | 13 | Uint16 | 0 to 6,500 mV | 1mV / bit and nil offset
High Cell Voltage | 15 | Uint16 | 0 to 6,500 mV | 1mV / bit and nil offset
Monitor Low Cell Temp | 17 | Bool | 0 or 1
Monitor High Cell Temp | 18 | Bool | 0 or 1
Low Cell Temp | 19 | Uint8 | -40ºC to 125ºC | 1ºC/bit and 40ºC offset
High Cell Temp | 20 | Uint8 | -40ºC to 125ºC | 1ºC/bit and 40ºC offset
Monitor Low Supply Voltage | 21 | Bool | 0 or 1
Monitor High Supply Voltage | 22 | Bool | 0 or 1
Low Supply Voltage | 23 | Uint16 | 0 to 65.00 V | Default multiple 100, defined with configuration
High Supply Voltage | 25 | Uint16 | 0 to 65.00 V | Default multiple 100, defined with configuration
Monitor Low Ambient Temp | 27 | Bool | 0 or 1
Monitor High Ambient Temp | 28 | Bool | 0 or 1
Low Ambient Temp | 29 | Uint8 | -40ºC to 125ºC | 1ºC/bit and 40ºC offset
High Ambient Temp | 30 | Uint8 | -40ºC to 125ºC | 1ºC/bit and 40ºC offset
Monitor Low Shunt Voltage | 31 | Bool | 0 or 1
Monitor High Shunt Voltage | 32 | Bool | 0 or 1
Monitor Low Idle Shunt Voltage | 33 | Bool | 0 or 1
Low Shunt Voltage | 34 | Uint16 | 0 to 65.00 V | Default multiple 100, defined with configuration
High Shunt Voltage | 36 | Uint16 | 0 to 65.00 V | Default multiple 100, defined with configuration
Low Idle Shunt Voltage | 38 | Uint16 | 0 to 65.00 V | Default multiple 100, defined with configuration
Monitor Shunt Voltage Peak Charge | 40 | Bool | 0 or 1
Shunt Peak Charge | 41 | Uint16
Shunt C-rate Charge | 43 | Uint16
Monitor Shunt Peak Discharge | 45 | Bool | 0 or 1
Shunt Peak Discharge | 46 | Uint16
Shunt C-rate Discharge | 48 | Uint16
Stop Timer Interval | 50 | Uint32 | | 1mS / bit and nil offset
Start Timer Interval | 54 | Uint32 | | 1mS / bit and nil offset
Time Out Manual Override | 58 | Uint32 | | 1mS / bit and nil offset
Setup Version | 62 | Uint8 | 0 to 255 | Incremental version number when saved to track when updates made

## Control Logic – Charging setup configuration info – payload formatting

Identifier: 0X5033
Frequency: 22 seconds
Data Length: 60 bytes
Version: 3
Field | Offset | Data Type | Format / Range | Resolution / Notes
Control Mode | 8 | Uint8 | 0 = Auto 1 = Manual ON 2 = Manual OFF 3 = Manual Limited Power
Allow Limited Power Stage | 9 | Bool | 0 or 1
Allow Limited Power Bypass | 10 | Bool | 0 or 1
Allow Limited Power Complete | 11 | Bool | 0 or 1
Initial Bypass Current | 12 | Uint16 | 0 to 2,500 mA | 1mA / bit and nil offset
Final Bypass Current | 14 | Uint16 | 0 to 2,500 mA | 1mA / bit and nil offset
Monitor Cell Low Temp | 16 | Bool | 0 or 1
Monitor Cell High Temp | 17 | Bool | 0 or 1
Cell Low Temp | 18 | Uint8 | -40ºC to 125ºC | 1ºC/bit and 40ºC offset
Cell High Temp | 19 | Uint8 | -40ºC to 125ºC | 1ºC/bit and 40ºC offset
Monitor Ambient Low Temp | 20 | Bool | 0 or 1
Monitor Ambient High Temp | 21 | Bool | 0 or 1
Ambient Low Temp | 22 | Uint8 | -40ºC to 125ºC | 1ºC/bit and 40ºC offset
Ambient High Temp | 23 | Uint8 | -40ºC to 125ºC | 1ºC/bit and 40ºC offset
Monitor Supply High | 24 | Bool | 0 or 1
Supply Voltage High | 25 | Uint16 | 0 to 65.00 V | Default multiple 100, defined with configuration
Supply Voltage Resume | 27 | Uint16 | 0 to 65.00 V | Default multiple 100, defined with configuration
Monitor High Cell Voltage | 29 | Bool | 0 or 1
Cell Voltage High | 30 | Uint16 | 0 to 6,500 mV | 1mV / bit and nil offset
Cell Voltage Resume | 32 | Uint16 | 0 to 6,500 mV | 1mV / bit and nil offset
Cell Voltage Limited Power | 34 | Uint16 | 0 to 6,500 mV | 1mV / bit and nil offset
Monitor Shunt Voltage High | 36 | Bool | 0 or 1
Shunt Voltage High | 37 | Uint16 | 0 to 65.00 V | Default multiple 100, defined with configuration
Shunt Voltage Resume | 39 | Uint16 | 0 to 65.00 V | Default multiple 100, defined with configuration
Shunt Voltage Limited Power | 41 | Uint16 | 0 to 65.00 V | Default multiple 100, defined with configuration
Monitor Shunt SoC High | 43 | Bool | 0 or 1
Shunt SoC High | 44 | Uint16 | -5% to +105% | 0.5% / bit and 5% offset
Shunt SoC Resume | 45 | Uint16 | -5% to +105% | 0.5% / bit and 5% offset
Stop Timer Interval | 46 | Uint32 | | 1mS / bit and nil offset
Start Timer Interval | 50 | Uint32 | | 1mS / bit and nil offset
Setup Version | 54 | Uint8 | 0 to 255 | Incremental version number when saved to track when updates made
Bypass Session Low | 55 | float | | mAh
Allow Bypass Session | 59 | Bool | 0 or 1

## Control Logic - Discharge Setup configuration info – payload formatting

Identifier: 0X5158
Frequency: 22 seconds
Data Length: 49 bytes
Version: 1
Field | Offset | Data Type | Format / Range | Resolution / Notes
Control Mode | 8 | Uint8 | 0 = Auto 1 = Manual ON 2 = Manual OFF 3 = Manual Limited Power
Allow Limited Power Stage | 9 | Bool | 0 or 1
Monitor Cell Temp Low | 10 | Bool | 0 or 1
Monitor Cell Temp High | 11 | Bool | 0 or 1
Cell Temp Low | 12 | Uint8 | -40ºC to 125ºC | 1ºC/bit and 40ºC offset
Cell Temp High | 13 | Uint8 | -40ºC to 125ºC | 1ºC/bit and 40ºC offset
Monitor Ambient Low | 14 | Bool | 0 or 1
Monitor Ambient High | 15 | Bool | 0 or 1
Ambient Temp Low | 16 | Uint8 | -40ºC to 125ºC | 1ºC/bit and 40ºC offset
Ambient Temp High | 17 | Uint8 | -40ºC to 125ºC | 1ºC/bit and 40ºC offset
Monitor Supply Low | 18 | Bool | 0 or 1
Supply Voltage Low | 19 | Uint16 | 0 to 65.00 V | Default multiple 100, defined with configuration
Supply Voltage Resume | 21 | Uint16 | 0 to 65.00 V | Default multiple 100, defined with configuration
Monitor Cell Voltage Lo | 23 | Bool | 0 or 1
Cell Voltage Low | 24 | Uint16 | 0 to 6,500 mV | 1mV / bit and nil offset
Cell Voltage Resume | 26 | Uint16 | 0 to 6,500 mV | 1mV / bit and nil offset
Cell Voltage Limited Power | 28 | Uint16 | 0 to 6,500 mV | 1mV / bit and nil offset
Monitor Shunt Voltage Low | 30 | Bool | 0 or 1
Shunt Voltage Low | 31 | Uint16 | 0 to 65.00 V | Default multiple 100, defined with configuration
Shunt Voltage Resume | 33 | Uint16 | 0 to 65.00 V | Default multiple 100, defined with configuration
Shunt Voltage Limited Power | 35 | Uint16 | 0 to 65.00 V | Default multiple 100, defined with configuration
Monitor Shunt SoC Low | 37 | Bool | 0 or 1
Shunt SoC Low | 38 | Uint8 | -5% to +105% | 0.5% / bit and 5% offset
Shunt SoC Resume | 39 | Uint8 | -5% to +105% | 0.5% / bit and 5% offset
Stop Timer Interval | 40 | Uint32 | | 1mS / bit and nil offset
Start Timer Interval | 44 | Uint32 | | 1mS / bit and nil offset
Setup Version | 48 | Uint8 | 0 to 255 | Incremental version number when saved to track when updates made

## Control Logic - Thermal Setup configuration info – payload formatting

Identifier: 0X5258
Frequency: 22 seconds
Data Length: 36 bytes
Version: 1
Field | Offset | Data Type | Format / Range | Resolution / Notes
Control Mode Heat | 8 | Uint8 | 0 = Auto 1 = Manual ON 2 = Manual OFF
Monitor Low Cell Temp | 9 | Bool | 0 or 1
Monitor Low Ambient Temp | 10 | Bool | 0 or 1
Low Cell Temp | 11 | Uint8 | -40ºC to 125ºC | 1ºC/bit and 40ºC offset
Low Ambient Temp | 12 | Uint8 | -40ºC to 125ºC | 1ºC/bit and 40ºC offset
Stop Timer Interval Heat | 13 | Uint32 | | 1mS / bit and nil offset
Start Timer Interval Heat | 17 | Uint32 | | 1mS / bit and nil offset
Control Mode Cool | 21 | Uint8 | 0 = Auto 1 = Manual ON 2 = Manual OFF
Monitor High Cell Temp | 22 | Bool | 0 or 1
Monitor High Ambient Temp | 23 | Bool | 0 or 1
Monitor In Cell Bypass | 24 | Bool | 0 or 1
High Cell Temp | 25 | uint8 | -40ºC to 125ºC | 1ºC/bit and 40ºC offset
High Ambient Temp | 26 | uint8 | -40ºC to 125ºC | 1ºC/bit and 40ºC offset
Stop Timer Interval Cool | 27 | Uint32 | | 1mS / bit and nil offset
Start Timer Interval Cool | 31 | Uint32 | | 1mS / bit and nil offset
Setup Version | 35 | Uint8 | 0 to 255 | Incremental version number when saved to track when updates made

## Control Logic - Remote Setup configuration info – payload formatting

Identifier: 0X4E58
Frequency: 22 seconds
Data Length: 45 bytes
Version: 1
Field | Offset | Data Type | Format / Range | Resolution / Notes
Charge Normal Volt | 8 | Uint16 | 0 to 65.00 V | Default multiple 100, defined with configuration
Charge Normal Amp | 10 | Uint16 | 0 to 650.00 A | Default multiple 100, defined with configuration (i.e. 0.01A / bit, 12000 = 120.0A)
Charge Normal VA | 12 | Uint16
Charge Limited Power Voltage | 14 | Uint16 | 0 to 65.00 V | Default multiple 100, defined with configuration
Charge Limited Power Amp | 16 | Uint16 | 0 to 650.00 A | Default multiple 100, defined with configuration (i.e. 0.01A / bit, 12000 = 120.0A)
Charge Limited Power VA | 18 | Uint16
Charge Scale16 Voltage | 20 | Uint16 | | Default multiple 100
Charge Scale16 Amp | 22 | Uint16 | | Default multiple 100
Charge Scale16 VA | 24 | Uint16 | | Default multiple 1
Discharge Normal Volt | 26 | Uint16 | 0 to 65.00 V | Default multiple 100, defined with configuration
Discharge Normal Amp | 28 | Uint16 | 0 to 650.00 A | Default multiple 100, defined with configuration (i.e. 0.01A / bit, 12000 = 120.0A)
Discharge Normal VA | 30 | Uint16
Discharge Limited Power Voltage | 32 | Uint16 | 0 to 65.00 V | Default multiple 100, defined with configuration
Discharge Limited Power Amp | 34 | Uint16 | 0 to 650.00 A | Default multiple 100, defined with configuration (i.e. 0.01A / bit, 12000 = 120.0A)
Discharge Limited Power VA | 36 | Uint16
Discharge Scale16 Voltage | 38 | Uint16 | | Default multiple 100
Discharge Scale16 Amp | 40 | Uint16 | | Default multiple 100
Discharge Scale16 VA | 42 | Uint16 | | Default multiple 1
Setup Version | 44 | Uint8 | 0 to 255 | Incremental version number when saved to track when updates made

## Telemetry – Daily session info – payload formatting

Identifier: 0X5432
Frequency: 22 seconds
Data Length: 69 bytes
Version: 2
Field | Offset | Data Type | Format / Range | Resolution / Notes
Min Cell Voltage | 8 | Uint16 | 0 to 6,500 mV | 1mV / bit and nil offset
Max Cell Voltage | 10 | Uint16 | 0 to 6,500 mV | 1mV / bit and nil offset
Min Supply Voltage | 12 | Uint16 | 0 to 65.00 V | 10mV / bit and nil offset
Max Supply Voltage | 14 | Uint16 | 0 to 65.00 V | 10mV / bit and nil offset
Min Reported Temperature | 16 | uint8 | -40ºC to 125ºC | 1ºC/bit and 40ºC offset #1
Max Reported Temperature | 17 | uint8 | -40ºC to 125ºC | 1ºC/bit and 40ºC offset #1
Min Shunt Volt | 18 | Uint16 | 0 to 65.00 V | Default multiple 100, defined with configuration
Max Shunt Volt | 20 | Uint16 | 0 to 65.00 V | Default multiple 100, defined with configuration
Min Shunt SoC | 22 | uint8 | -5% to +105% | 0.5% / bit and 5% offset
Max Shunt SoC | 23 | uint8 | -5% to +105% | 0.5% / bit and 5% offset
Temperature Band A > 60ºC | 24 | Uint8 | 0 to 240 | 6min/bit elapsed (240 = 24.0h)
Temperature Band B > 55ºC | 25 | Uint8 | 0 to 240 | 6min/bit elapsed (240 = 24.0h)
Temperature Band C > 41ºC | 26 | Uint8 | 0 to 240 | 6min/bit elapsed (240 = 24.0h)
Temperature Band D > 33ºC | 27 | Uint8 | 0 to 240 | 6min/bit elapsed (240 = 24.0h)
Temperature Band E > 25ºC | 28 | Uint8 | 0 to 240 | 6min/bit elapsed (240 = 24.0h)
Temperature Band F > 15ºC | 29 | Uint8 | 0 to 240 | 6min/bit elapsed (240 = 24.0h)
Temperature Band G > 0ºC | 30 | Uint8 | 0 to 240 | 6min/bit elapsed (240 = 24.0h)
Temperature Band H >-40ºC | 31 | Uint8 | 0 to 240 | 6min/bit elapsed (240 = 24.0h)
SOC% Band A > 87.5% | 32 | Uint8 | 0 to 240 | 6min/bit elapsed (240 = 24.0h)
SOC% Band B > 75.0% | 33 | Uint8 | 0 to 240 | 6min/bit elapsed (240 = 24.0h)
SOC% Band C > 62.5% | 34 | Uint8 | 0 to 240 | 6min/bit elapsed (240 = 24.0h)
SOC% Band D > 50.0% | 35 | Uint8 | 0 to 240 | 6min/bit elapsed (240 = 24.0h)
SOC% Band E > 37.5% | 36 | Uint8 | 0 to 240 | 6min/bit elapsed (240 = 24.0h)
SOC% Band F > 25.0% | 37 | Uint8 | 0 to 240 | 6min/bit elapsed (240 = 24.0h)
SOC% Band G > 12.5% | 38 | Uint8 | 0 to 240 | 6min/bit elapsed (240 = 24.0h)
SOC% Band H > 0.0% | 39 | Uint8 | 0 to 240 | 6min/bit elapsed (240 = 24.0h)
Shunt Peak Charge | 40 | Uint16 | 0.01A / bit | Default multiple 100, defined with configuration
Shunt Peak Discharge | 42 | Uint16 | 0.01A / bit | Default multiple 100, defined with configuration
Critical Events | 44 | Uint8 | 0 to 255 | Number of events within session
Start Time | 45 | Uint32 | Unix Epoch | seconds since 1-1-1970
Finish Time | 49 | Uint32 | Unix Epoch | seconds since 1-1-1970
Cumulative Shunt Amp Hour Charge | 53 | Float | Reported in mAh | Total counted in 1 min intervals
Cumulative Shunt Amp Hour Discharge | 57 | Float | Reported in mAh | Total counted in 1 min intervals
Cumulative Shunt Watt Hour Charge | 61 | Float | Reported in VA hr
Cumulative Shunt Watt Hour Discharge | 65 | Float | Reported in VA hr

## Telemetry – Daily session History reply – payload formatting

Identifier: 0X5831
Frequency: adhoc
Data Length: 60 bytes
Version: 1
Field | Offset | Data Type | Format / Range | Resolution / Notes
Record Index | 8 | Uint16
Record Time | 10 | Uint32 | Unix Epoch | seconds since 1-1-1970
Critical Events | 14 | Uint8 | 0 to 255 | Number of events within session
| 15 | | | Reserved
Min Reported Temperature | 16 | uint8 | -40ºC to 125ºC | 1ºC/bit and 40ºC offset #1
Max Reported Temperature | 17 | uint8 | -40ºC to 125ºC | 1ºC/bit and 40ºC offset #1
Min Shunt SoC | 18 | uint8 | -5% to +105% | 0.5% / bit and 5% offset
Max Shunt SoC | 19 | uint8 | -5% to +105% | 0.5% / bit and 5% offset
Min Cell Voltage | 20 | Uint16 | 0 to 6,500 mV | 1mV / bit and nil offset
Max Cell Voltage | 22 | Uint16 | 0 to 6,500 mV | 1mV / bit and nil offset
Min Supply Voltage | 24 | Uint16 | 0 to 65.00 V | 10mV / bit and nil offset
Max Supply Voltage | 26 | Uint16 | 0 to 65.00 V | 10mV / bit and nil offset
Min Shunt Volt | 28 | Uint16 | 0 to 65.00 V | Default multiple 100, defined with configuration
Max Shunt Volt | 30 | Uint16 | 0 to 65.00 V | Default multiple 100, defined with configuration
Temperature Band A > 60ºC | 32 | Uint8 | 0 to 240 | 6min/bit elapsed (240 = 24.0h)
Temperature Band B > 55ºC | 33 | Uint8 | 0 to 240 | 6min/bit elapsed (240 = 24.0h)
Temperature Band C > 41ºC | 34 | Uint8 | 0 to 240 | 6min/bit elapsed (240 = 24.0h)
Temperature Band D > 33ºC | 35 | Uint8 | 0 to 240 | 6min/bit elapsed (240 = 24.0h)
Temperature Band E > 25ºC | 36 | Uint8 | 0 to 240 | 6min/bit elapsed (240 = 24.0h)
Temperature Band F > 15ºC | 37 | Uint8 | 0 to 240 | 6min/bit elapsed (240 = 24.0h)
Temperature Band G > 0ºC | 38 | Uint8 | 0 to 240 | 6min/bit elapsed (240 = 24.0h)
Temperature Band H >-40ºC | 39 | Uint8 | 0 to 240 | 6min/bit elapsed (240 = 24.0h)
SOC% Band A > 87.5% | 40 | Uint8 | 0 to 240 | 6min/bit elapsed (240 = 24.0h)
SOC% Band B > 75.0% | 41 | Uint8 | 0 to 240 | 6min/bit elapsed (240 = 24.0h)
SOC% Band C > 62.5% | 42 | Uint8 | 0 to 240 | 6min/bit elapsed (240 = 24.0h)
SOC% Band D > 50.0% | 43 | Uint8 | 0 to 240 | 6min/bit elapsed (240 = 24.0h)
SOC% Band E > 37.5% | 44 | Uint8 | 0 to 240 | 6min/bit elapsed (240 = 24.0h)
SOC% Band F > 25.0% | 45 | Uint8 | 0 to 240 | 6min/bit elapsed (240 = 24.0h)
SOC% Band G > 12.5% | 46 | Uint8 | 0 to 240 | 6min/bit elapsed (240 = 24.0h)
SOC% Band H > 0.0% | 47 | Uint8 | 0 to 240 | 6min/bit elapsed (240 = 24.0h)
Shunt Peak Charge | 48 | Uint16 | 0.01A / bit | Default multiple 100, defined with configuration
Shunt Peak Discharge | 50 | Uint16 | 0.01A / bit | Default multiple 100, defined with configuration
Cumulative Shunt Amp Hour Charge | 52 | Float | Reported in mAh | Total counted in 1 min intervals
Cumulative Shunt Amp Hour Discharge | 56 | Float | Reported in mAh | Total counted in 1 min intervals

## Telemetry – Quick session History reply – payload formatting

Identifier: 0X6831
Frequency: adhoc
Data Length: 32 bytes
Version: 1
Field | Offset | Data Type | Format / Range | Resolution / Notes
Record Index | 8 | Uint16
Record Time | 10 | Uint32 | Unix Epoch | seconds since 1-1-1970
System Op status | 14 | Uint8 | Timeout = 0, Idle = 1, // LED = green slow pulse Charging = 2, // LED = blue slow pulse Discharging = 3, // LED = green solid Full = 4, // LED = blue double blink Empty = 5, // LED = green double blink Simulator = 6 , // LED = rainbow pulse Critical Pending = 7, // LED = red fast pulse Critical Offline = 8, // LED = red slow pulse Mqtt Offline = 9, // LED = white blink Auth Setup = 10, // LED = white solid
Control Flags | 15 | Byte | Bit 0 = Critical Relay Bit 1 = Charging High Power Bit 2 = Charging Limited Power Bit 3 = Discharge High Power Bit 4 = Discharge Limited Power Bit 5 = Cooling required Bit 6 = Heating required
Min Cell Voltage | 16 | Uint16 | 0 to 6,500 mV | 1mV / bit and nil offset
Max Cell Voltage | 18 | Uint16 | 0 to 6,500 mV | 1mV / bit and nil offset
Avg Cell Voltage | 20 | Uint16 | 0 to 6,500 mV | 1mV / bit and nil offset
Avg Temperature | 22 | uint8 | -40ºC to 125ºC | 1ºC/bit and 40ºC offset #1
Shunt SoC% HiRes | 23 | Int16 | -5.00% to +105.00% | 0.01% / bit
Shunt Volt | 25 | Uint16 | 0 to 65.00 V | Default multiple 100, defined with configuration
Shunt Current (A) | 27 | float | 1mA / bit
Number of cells in Bypass | 31 | Uint8 | 0 to 255

## Telemetry – Session metrics info – payload formatting

Identifier: 0X5431
Frequency: adh0c
Data Length: 25 bytes
Version: 1
Field | Offset | Data Type | Format / Range | Resolution / Notes
Recent Time Quick Session | 8 | Uint32 | Unix Epoch | seconds since 1-1-1970
Quick session number of records | 12 | Uint16
Quick session record capacity | 14 | Uint16
Quick Session Interval | 16 | Uint32 | | 1bit/mS
Allow Quick Session | 20 | Bool | 0 or 1
Daily session number of records | 21 | Uint16
Daily session record capacity | 23 | Uint16

## Telemetry – Shunt metrics info – payload formatting

Identifier: 0X7857
Frequency: 22 seconds
Data Length: 76 bytes
Field | Offset | Data Type | Format / Range | Resolution / Notes
Shunt SoC Cycles | 8 | Uint16
Last Time Accumulation Saved | 10 | Uint32 | Unix Epoch | seconds since 1-1-1970
Last Time SoC Lo Recal | 14 | Uint32 | Unix Epoch | seconds since 1-1-1970
Last Time SoC Hi Recal | 18 | Uint32 | Unix Epoch | seconds since 1-1-1970
Last Time SoC Lo Count | 22 | Uint32 | Unix Epoch | seconds since 1-1-1970
Last Time SoC Hi Count | 26 | Uint32 | Unix Epoch | seconds since 1-1-1970
Has Shunt SoC Lo Count | 30 | Bool | 0 or 1
Has Shunt SoC Hi Count | 31 | Bool | 0 or 1
Estimated Duration to Full in minutes | 32 | Uint16
Estimated Duration to Empty in minutes | 34 | Uint16
Recent Charge in Avg mAh | 36 | Float
Recent Discharge in Avg mAh | 40 | Float
Recent Nett mAh | 44 | Float
Serial Number | 48 | Uint32
Manu Code | 52 | Uint32
Part Number | 56 | Uint16
Version Code | 58 | Uint16
PNS1 | 60 | Text 8
PNS2 | 68 | Text 8

## Telemetry – Lifetime metrics info – payload formatting

Identifier: 0X5632
Frequency: 22 seconds
Data Length: 115 bytes
Version 2
Field | Offset | Data Type | Format / Range | Resolution / Notes
First Sync Time | 8 | Uint32 | Unix Epoch | seconds since 1-1-1970
Count Startup | 12 | Uint32 | | 1 event ON / bit
Count Critical Battery OK | 16 | Uint32 | | 1 event ON / bit
Count Charge On | 20 | Uint32 | | 1 event ON / bit
Count Charge Limited Power | 24 | Uint32 | | 1 event ON / bit
Count Discharge On | 28 | Uint32 | | 1 event ON / bit
Count Discharge Limited Power | 32 | Uint32 | | 1 event ON / bit
Count Heat On | 36 | Uint32 | | 1 event ON / bit
Count Cool On | 40 | Uint32 | | 1 event ON / bit
Count Daily Session | 44 | Uint16 | | 1 event ON / bit
Most Recent Time Critical On | 46 | Uint32 | Unix Epoch | seconds since 1-1-1970
Most Recent Time Critical Off | 50 | Uint32 | Unix Epoch | seconds since 1-1-1970
Most Recent Time Charge On | 54 | Uint32 | Unix Epoch | seconds since 1-1-1970
Most Recent Time Charge Off | 58 | Uint32 | Unix Epoch | seconds since 1-1-1970
Most Recent Time Charge Limited Power | 62 | Uint32 | Unix Epoch | seconds since 1-1-1970
Most Recent Time Discharge On | 66 | Uint32 | Unix Epoch | seconds since 1-1-1970
Most Recent Time Discharge Off | 70 | Uint32 | Unix Epoch | seconds since 1-1-1970
Most Recent Time Discharge Limited Power | 74 | Uint32 | Unix Epoch | seconds since 1-1-1970
Most Recent Time Heat On | 78 | Uint32 | Unix Epoch | seconds since 1-1-1970
Most Recent Time Heat Off | 82 | Uint32 | Unix Epoch | seconds since 1-1-1970
Most Recent Time Cool On | 86 | Uint32 | Unix Epoch | seconds since 1-1-1970
Most Recent Time Cool Off | 90 | Uint32 | Unix Epoch | seconds since 1-1-1970
Most Recent Time Bypass Initialised | 94 | Uint32 | Unix Epoch | seconds since 1-1-1970
Most Recent Time Bypass Completed | 98 | Uint32 | Unix Epoch | seconds since 1-1-1970
Most Recent Time Bypass Tested | 102 | Uint32 | Unix Epoch | seconds since 1-1-1970
Recent Bypass Outcomes | 106 | Uint8 | 0 = Not Tested, 1 = Preparing, 2 = Testing, 3 = Passed Ok, 4 = Failed,
Most Recent Time wizard setup | 107 | Uint32 | Unix Epoch | seconds since 1-1-1970
Most Recent Time Rebalancing Extra | 111 | Uint32 | Unix Epoch | seconds since 1-1-1970

## Telemetry - Cellmon node status info – payload formatting

Identifier: 0X415A
Frequency: 22 seconds
Data Length: variable
Version 1
Field | Offset | Data Type | Format / Range | Resolution / Notes
CMU Port – RX Node ID | 8 | Uint8
Records | 9 | Uint8
First Node ID | 10 | Uint8 | | Node Identifier
Last Node ID | 11 | Uint8 | | Node Identifier
Node ID | idx+0
USN | Idx+1
Min Cell Voltage | Idx+2 | Uint16 | 0 to 6,500 mV | 1mV / bit and nil offset
Max Cell Voltage | Idx+4 | Uint16 | 0 to 6,500 mV | 1mV / bit and nil offset
Max Cell Temp | Idx+6 | Uint8 | -40ºC to 125ºC | 1ºC/bit and 40ºC offset
Bypass Temp | Idx+7 | Uint8 | -40ºC to 125ºC | 1ºC/bit and 40ºC offset
Bypass Amp | Idx+8 | Uint16 | 0 to 2,500 mA | 1mA / bit and nil offset
Node Status | Idx+10 | Uint8 | None = 0, HighVolt = 1, HighTemp = 2, Ok = 3, Timeout = 4, LowVolt = 5, Disabled = 6, InBypass = 7, InitialBypass = 8, FinalBypass = 9, MissingSetup = 10, NoConfig = 11, CellOutLimits = 12, Undefined = 255,

This contains and array of up to 16 cell modules

## Telemetry - Cellmon node full info – payload formatting

Identifier: 0X4232
Data Length: 52 bytes
Version 2
Field | Offset | Data Type | Format / Range | Resolution / Notes
Node ID | 8 | Uint8 | | Node Identifier
USN | 9 | Uint8
Min Cell Voltage | 10 | Uint16 | 0 to 6,500 mV | 1mV / bit and nil offset
Max Cell Voltage | 12 | Uint16 | 0 to 6,500 mV | 1mV / bit and nil offset
Max Cell Temp | 14 | Uint8 | -40ºC to 125ºC | 1ºC/bit and 40ºC offset
Bypass Temp | 15 | Uint8 | -40ºC to 125ºC | 1ºC/bit and 40ºC offset
Bypass Amp | 16 | Uint16 | 0 to 2,500 mA | 1mA / bit and nil offset
Error Data Counter | 18 | Uint8
Reset Counter | 19 | Uint8
Operating Status | 20 | Uint8 | None = 0, HighVolt = 1, HighTemp = 2, Ok = 3, Timeout = 4, LowVolt = 5, Disabled = 6, InBypass = 7, InitialBypass = 8, FinalBypass = 9, MissingSetup = 10, NoConfig = 11, CellOutLimits = 12, Undefined = 255,
Is Overdue | 21 | Bool | 0 or 1
Param - Low Cell Voltage | 22 | Uint16 | 0 to 6,500 mV | 1mV / bit and nil offset
Param - High Cell Voltage | 24 | Uint16 | 0 to 6,500 mV | 1mV / bit and nil offset
Param - Bypass Voltage Level | 26 | Uint16 | 0 to 6,500 mV | 1mV / bit and nil offset
Param - Bypass Amp | 28 | Uint16 | 0 to 2,500 mA | 1mA / bit and nil offset
Param - Bypass Temp Limit | 30 | Uint8 | -40ºC to 125ºC | 1ºC/bit and 40ºC offset
Param – High Cell Temp | 31 | Uint8 | -40ºC to 125ºC | 1ºC/bit and 40ºC offset
Param – Raw Volt Cal Offset | 32 | Uint8
Device – FW version | 33 | Uint16
Device – HW version | 35 | Uint16
Device – Boot version | 37 | Uint16
Device – Serial Num | 39 | Uint32
Bypass Initial Date | 43 | Uint32 | Unix Epoch | seconds since 1-1-1970
Bypass Session mAh | 47 | Float | | Session milli Amp Hour
Repeat CellV | 51 | Uint8 | 0 to 250 | Counter when same

## Legacy Outbound message type register

List of legacy message types available in the previous software versions

Msg Type | Description | SW Vers Introduced | SW Vers Depreciated
0x4A59 | Hardware – System setup v1
0x4A58 | Hardware – System setup v2 | | 1.0.21
0x4A33 | Hardware – System setup v3 | | 1.0.28
0x4A34 | Hardware – System setup v4 | | 1.0.29
0x4B59 | Hardware – Cellmon setup v1
0x4B58 | Hardware – Cellmon setup v2 | | 1.0.23
0x4B33 | Hardware – Cellmon setup v3 | | 1.0.24
0x4B34 | Hardware – Cellmon setup v4 | | 1.0.29
0x4C59 | Hardware – Shunt setup v1
0x4C58 | Hardware – Shunt setup v2 | | 1.0.29
0x4D59 | Hardware – Expansion setup v1
0x4D58 | Hardware – Expansion setup v2 | | 1.0.26
0x5359 | Hardware - Integration setup v1
0x5358 | Hardware - Integration setup v2 | | 1.0.21
0x5333 | Hardware - Integration setup v3 | | 1.0.26
0x4F59 | Control – Critical setup v1
0x4F58 | Control – Critical setup v2
0x4F33 | Control – Critical setup v3 | | 1.0.27
0x5059 | Control – Charging setup v1
0x5058 | Control – Charging setup v2 | | 1.0.21
0x5159 | Control – Discharging setup v1
0x5259 | Control – Thermal setup v1
0x4E59 | Control – Remote setup v1
0x495A | Control – Remote status v1 | | 1.0.21
0x5775 | Telemetry – System Discovery v1 | | 1.0.21
0x435A | Telemetry – Combined Rapid statistics v1
0x3E5A | Telemetry – Combined Rapid status v1 | | 1.0.29
0x3F5A | Telemetry – Combined Fast status v1 | | 1.0.21
0x3F32 | Telemetry – Combined Fast status v2 | | 1.0.23
0x405A | Telemetry – Combined Slow v1 | | 1.0.28
0x475A | Telemetry – Control Logic status v1
0x485A | Telemetry – System Extension status v1
0x5657 | Telemetry – Lifetime metrics v1 | | 1.0.23
0x425A | Telemetry – Cellmon node full details v1 | | 1.0.23

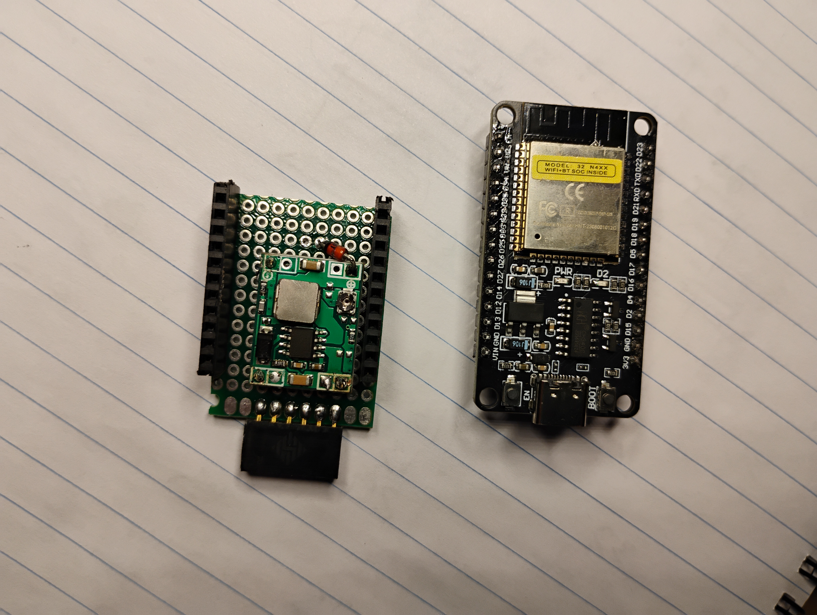
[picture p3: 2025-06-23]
pics/01_esp32_and_motherboard.jpg

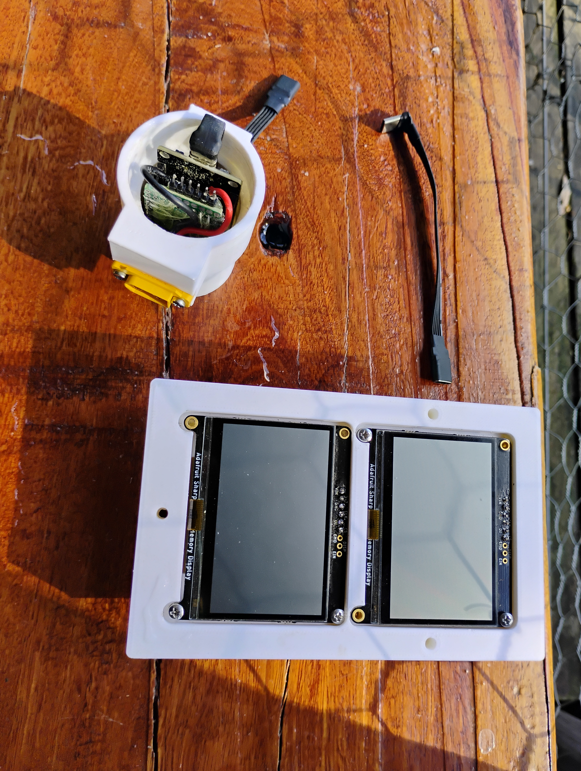
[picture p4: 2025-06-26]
pics/08_displays_mounted_usb_cable_arrived.jpg

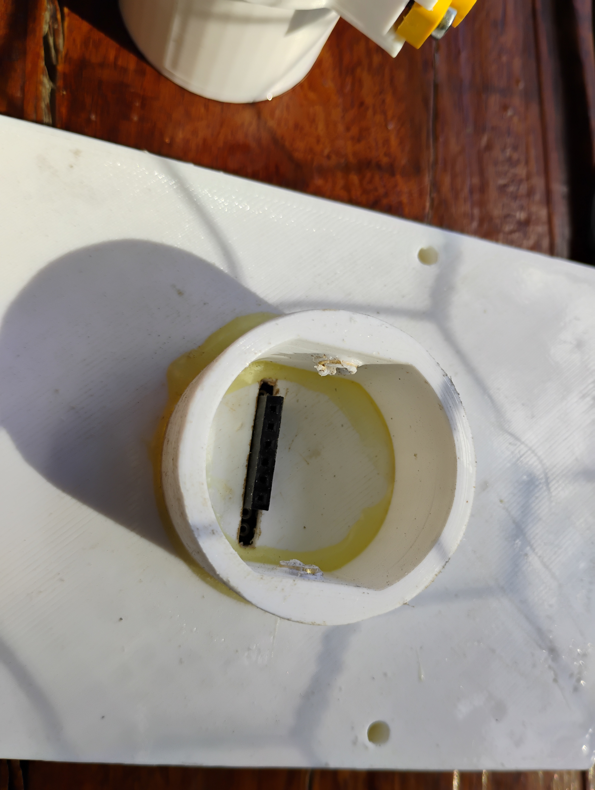
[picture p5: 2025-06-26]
pics/11_back_of_front.jpg

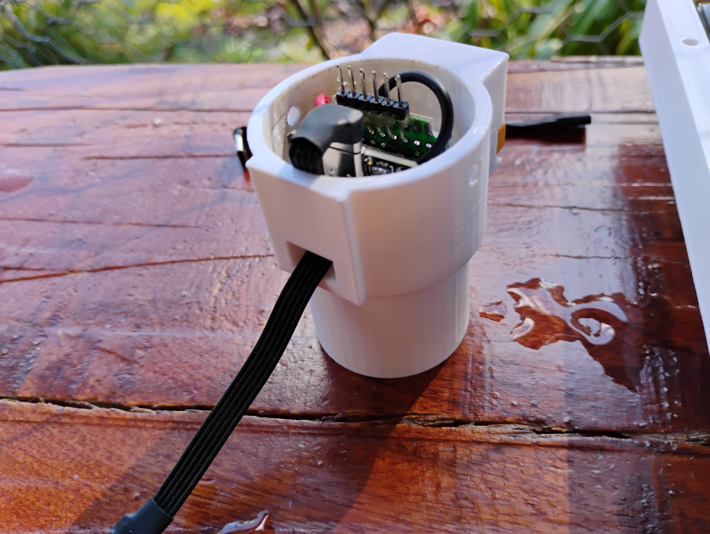
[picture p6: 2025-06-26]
pics/09_usb.jpg

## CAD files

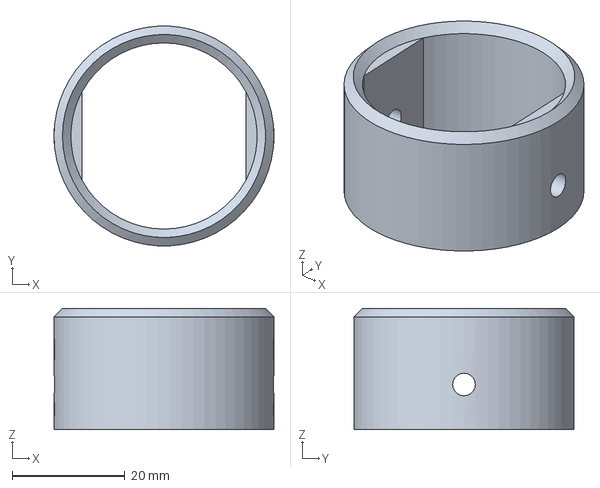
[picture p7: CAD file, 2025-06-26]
cad/dd_spigot.FCStd
39.0 x 38.9 x 21.5 mm

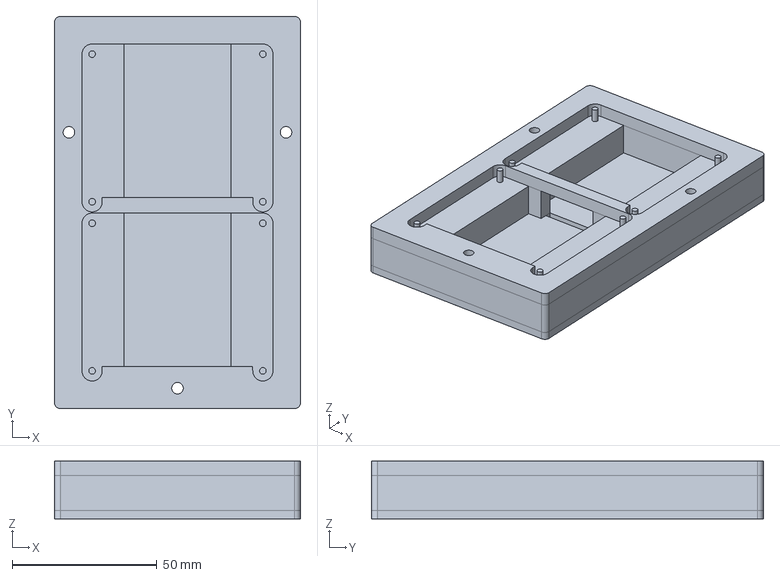
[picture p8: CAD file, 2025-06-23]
cad/dd_front_nospigot.FCStd
85.0 x 135.4 x 20.0 mm

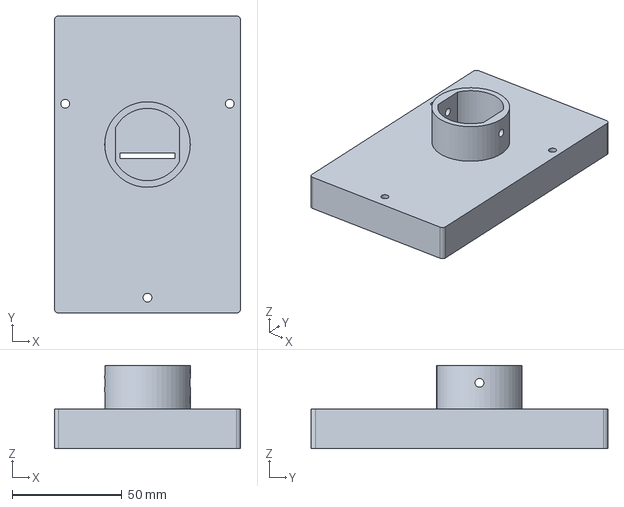
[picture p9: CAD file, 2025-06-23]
cad/dd_3.FCStd
85.0 x 135.4 x 38.0 mm

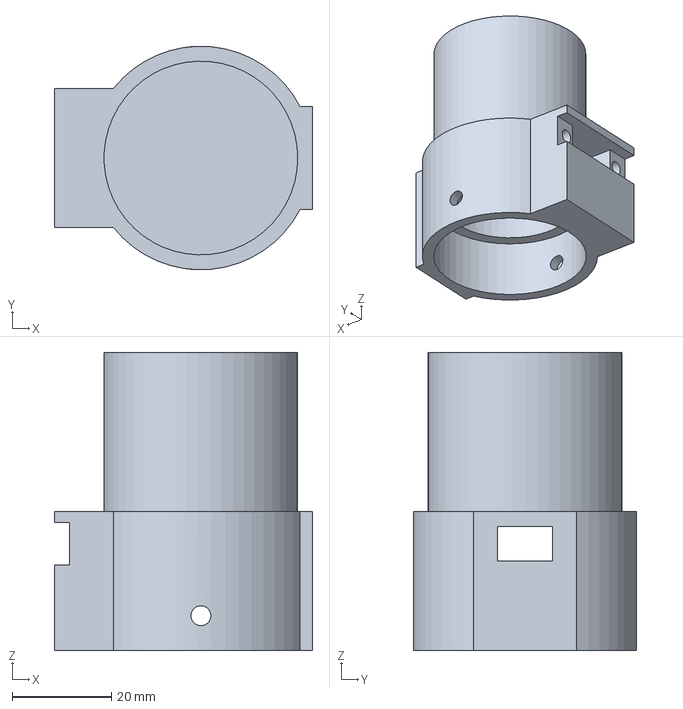
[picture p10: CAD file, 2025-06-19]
cad/dd3_back2.FCStd
52.0 x 45.0 x 60.0 mm

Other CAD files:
cad/dd_back.3mf
cad/dd_3_front.3mf
cad/dd_3_front.stl
cad/dd_back.stl
cad/dd_front_nospigot.stl
cad/dd_spigot.stl

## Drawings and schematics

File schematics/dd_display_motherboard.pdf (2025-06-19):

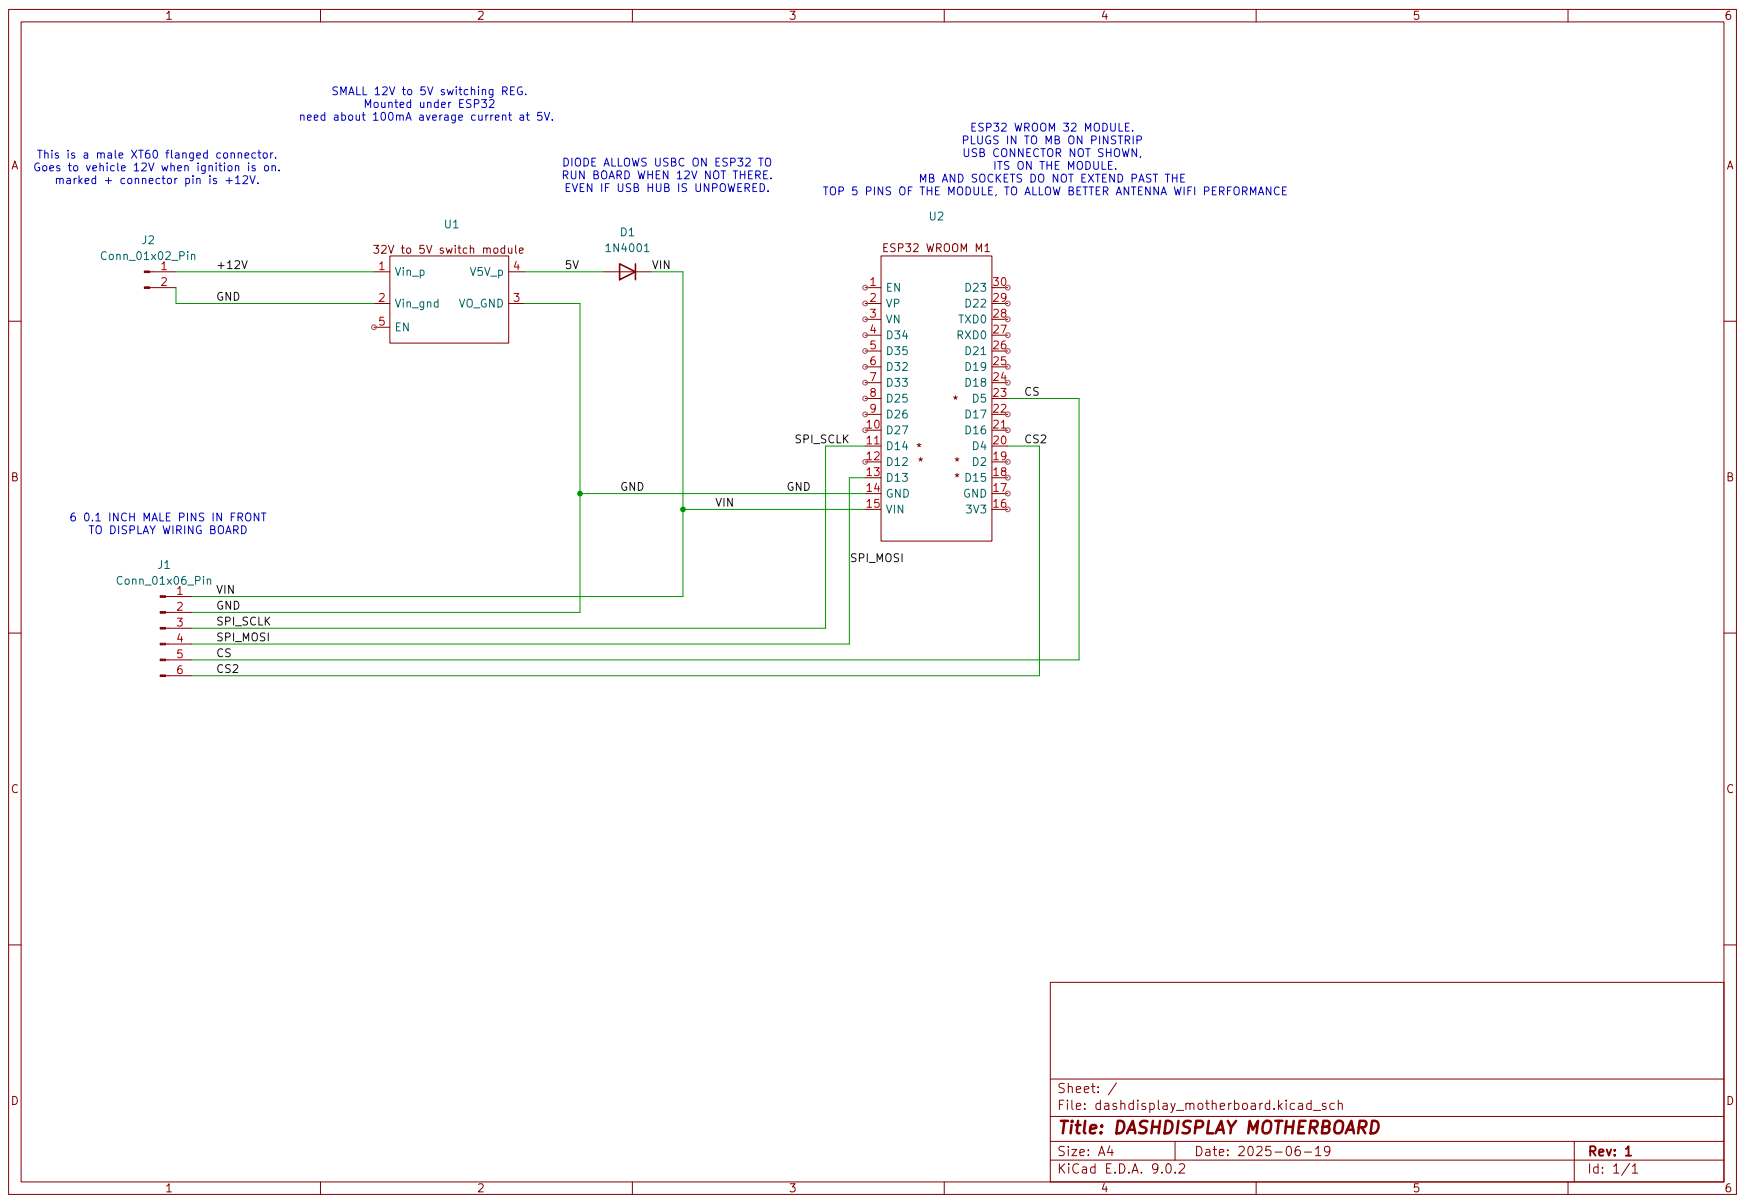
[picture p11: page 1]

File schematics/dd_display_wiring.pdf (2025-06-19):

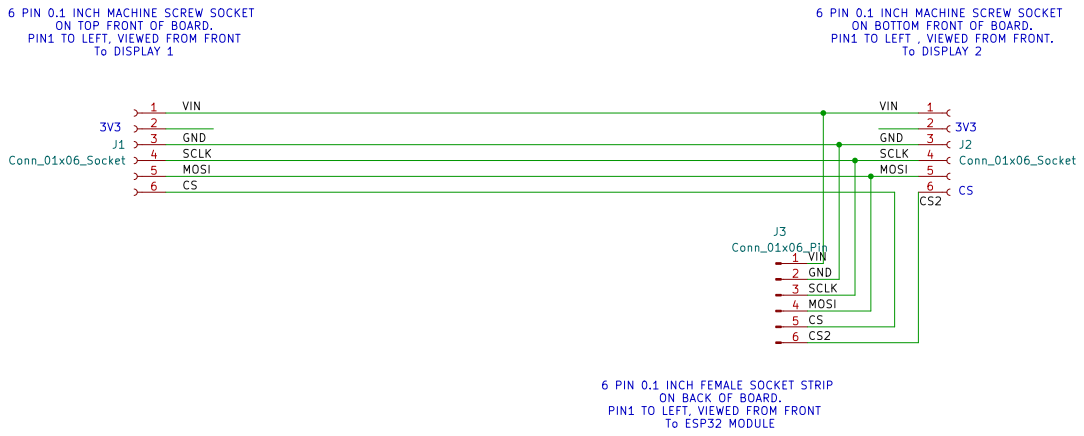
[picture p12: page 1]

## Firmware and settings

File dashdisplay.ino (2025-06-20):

//    -*- Mode: c++     -*-
// my $ver =  'display  Time-stamp: "2025-06-20 16:41:08 john"';

/* All code in this directory written by me and is BSD licensed.
   John Sheahan June 2025
/*********************************************************************
This is the second cut of the dash display for the haflinger. This time its going to
connect to the AP set up by the batrium BMS, 

It uses parts of:
   the adafruit example sketch for their Monochrome SHARP Memory Displays
   Written by Limor Fried/Ladyada  for Adafruit Industries.
   BSD license, check license.txt for more information
   All text above, must be included in any redistribution
   However I think the only thing I have replicated is calls to Adafruits libraries.
   I don't claim to own the call lines.
   
   This thing contains 2 adafruit sharp displays, just displays what remote sensors send to it.  
    (Did I get these from Core electronics or adafruit? not sure now. Core are a local reseller)

   Various code fragments from my mower upgrade project too. All my own work I think.
   And from my Cattleyards gadget.

POSSIBLE extensions
  Consider a switch to control the fans in the battery boxes. Thinking switching them off for a big puddle might make sense.
  Consider a rotary encoder to control more general things. Apparently I can treat some of the flash as EE. Although some ee might be nice if I want say a distance or maybe hour meter. 

*********************************************************************/
#include "display_data.h"

// Set the IO pins used, and size of the displays

Adafruit_SharpMem display1(SHARP_SCK, SHARP_MOSI, SHARP_CS, display_h_pixels, display_v_pixels);
Adafruit_SharpMem display2(SHARP_SCK, SHARP_MOSI, SHARP_2CS, display_h_pixels, display_v_pixels);

void setup(void)
{
  
  Serial.begin(115200);
  Serial.println(version);
  delay(50);

  // start & clear the displays
  display1.begin();
  display1.clearDisplay();
  display1.setRotation(0);

  display2.begin();
  display2.clearDisplay();
  display2.setRotation(0);
  
  Serial.println("init NVM");
  // initialize NVM  
   dispPrefs.begin("dispPrefs", RO_MODE);     // Open our namespace (or create it if it doesn't exist)
   bool tpInit = dispPrefs.isKey("nvsInit"); // Test for the existence of the "already initialized" key.
   dispPrefs.end();                          // close the namespace in RO mode
   if (tpInit == false) 
     reinit_NVM();                          // reinitialize the nvm structure if magik key was missing 
   
   // load local variables from NVM
   load_operational_params();                // initialize RAM variables from NVM

   // init some general variables and IOs 
   serial_buf_pointer = 0;
   last_display_update_time = millis();
   last_connect_check_time = millis();

   initWiFi();
   Serial.println("Connected to wifi");
   udp.begin(batrium_port);
  
   // Enable WiFi power-saving workaround for UDP broadcast.
   // wifi_set_ps(WIFI_PS_MIN_MODEM);

   // Enable broadcast on the socket
   //   int broadcastEnable = 1;
   //int sock = udp.getSocket(); // Get the underlying socket descriptor
   //setsockopt(sock, SOL_SOCKET, SO_BROADCAST, &broadcastEnable, sizeof(broadcastEnable));

   Serial.println("done setup");
   
}

void loop(void) 
{
  char outbuf[20];
  
  // update display(s) if display variables have changed.
  // refresh display at least once per second, 
  if (millis() >= (last_display_update_time + display_update_millis) )
    {
      if (new_data)
	{
	  display1.clearDisplay();
	  display1.setTextSize(6);
	  display1.setTextColor(BLACK);
	  // pack voltage
	  display1.setCursor(d1_xy.pack_v_x, d1_xy.pack_v_y);
	  sprintf(outbuf, "%3d.%02dV", dd_data.pack_v/100, dd_data.pack_v % 100);
	  display1.print(outbuf);

	  // pack I
	  display1.setCursor(d1_xy.pack_i_x, d1_xy.pack_i_y);
	  sprintf(outbuf, "%4.3fA", dd_data.pack_i/1000.0f);
	  display1.print(outbuf);

	  // SOC
	  display1.setCursor(d1_xy.pack_soc_x, d1_xy.pack_soc_y);
	  sprintf(outbuf, "%3d.%1d%%", (dd_data.pack_soc -10)/2, 5*(dd_data.pack_soc % 2));
	  display1.print(outbuf);
	}
	  
      display1.refresh();

      if (new_data)
	{
	  display2.clearDisplay();
	  display2.setTextSize(5);
	  display2.setTextColor(BLACK);
	  display2.setCursor(d2_xy.cell_min_v_x, d2_xy.cell_min_v_y);
	  sprintf(outbuf, "min=%1d.%03dV", dd_data.cell_min_v/1000, dd_data.cell_min_v % 1000);
	  display2.print(outbuf);
	  
	  display2.setCursor(d2_xy.cell_max_v_x, d2_xy.cell_max_v_y);
	  sprintf(outbuf, "max=%1d.%03d", dd_data.cell_max_v/1000, dd_data.cell_max_v % 1000);
	  display2.print(outbuf);
	  
	  display2.setCursor(d2_xy.cell_min_t_x, d2_xy.cell_min_t_y);
	  sprintf(outbuf, "min=%2dC", dd_data.cell_min_t);
	  display2.print(outbuf);
	  
	  display2.setCursor(d2_xy.cell_max_t_x, d2_xy.cell_max_t_y);
	  sprintf(outbuf, "max=%2dC", dd_data.cell_max_t);
	  display2.print(outbuf);
	  new_data = false;
	}
      
      display2.refresh();
      last_display_update_time = millis();
    }
  // service serial character if any available.
  do_serial_if_ready();
  
  // check for a packet
  int packetSize = udp.parsePacket();
  if (packetSize)
    {
      uint8_t len = udp.read(udp_buffer, 255);
      if (len >= 3) 
	{
	  parse_udp();
	}
    }  
  
  
  // if WiFi is down, try reconnecting
  if ((WiFi.status() != WL_CONNECTED) && (millis() >= (last_connect_check_time + connect_check_millis))) {
    Serial.print(millis());
    Serial.println("Reconnecting to WiFi...");
    WiFi.disconnect();
    WiFi.reconnect();
    last_connect_check_time = millis();
  }
}    

    


void initWiFi( void)
{
  uint8_t retries = 0;
  WiFi.mode(WIFI_STA);
  WiFi.begin(ssid, password);
  Serial.print("Connecting to WiFi ..");
  while ((WiFi.status() != WL_CONNECTED) && (retries < 10)) {
    Serial.print('.');
    delay(1000);
    retries++;
  }
  Serial.println(WiFi.localIP());
}

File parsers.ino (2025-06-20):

//    -*- Mode: c++     -*-
// emacs automagically updates the timestamp field on save
// my $ver =  'parsers for display  Time-stamp: "2025-06-20 16:40:14 john"';

// this is the parsers for app to run the display parser for the haflinger
// use tools -> board ->  ESP32 Dev module 


// this is for Serial 0, debug and writing NVM
// 
void parse_buf (char * in_buf)
{
  // Z  eraZe NV memory
  // Rf Read and print Field,
  //    where Field could be    
  //          RP\n   show the stored wifi password
  //          RS\n   show stored wifi ssid
  //          V\n    show software version
  // Wf Write Field to NVM,
  //    where Field could be (variable data to write is in lower case here hopefully fpr clarity. just Type the case you want however)
  //          WP=passsword\n   set wifi Password to "password"
  //          WS=ssid\n        set wifi Ssid  to "ssid
  //                        

  int8_t  address;
  uint8_t  cmd;
  int      value;
  uint8_t  mvalue[6]; // mac address
  float    fvalue;
  const uint8_t out_buf_len = 20;
  char     out_buf[out_buf_len];
  int      match ;
  int      i;
  int32_t soc;
  uint32_t time1;
  uint32_t time2;
  
  cmd = in_buf[0];
  
  switch (cmd)
    {
    case 'Z':
      reinit_NVM();
      load_operational_params();
      break;
      
    case 'R':
      switch (in_buf[1])
	{
	case 'S':
	  Serial.printf("SSID=%20s\n", ssid);
	  break;

	case 'P':
	  Serial.printf("PASSWORD=%20s\n", password);
	  break;
	  
	case 'V':
	  Serial.println(version);
	  break;
	}
      break;
      
    case 'W':
      switch (in_buf[1]) {
	
      case 'P' :
	// nope, I cannot make sscanf work for a char then a 0 terminated string. So do a manual scan
	//	Serial.printf("input to parser is %s len %d\n", in_buf, strlen(in_buf));
	strncpy(out_buf, in_buf+3,  20); // hop over WP= 
	//Serial.print("got len=");
	//Serial.print(strlen(out_buf));
	//Serial.print(" c1=");
	//Serial.print(in_buf+3);
	//Serial.print("= ");
	
	//Serial.print(" str=");
	//Serial.print(out_buf);
	//Serial.println("=");
	
	dispPrefs.begin("dispPrefs", RW_MODE);
	dispPrefs.putString("password",  out_buf);
	dispPrefs.end();
	load_operational_params();
	break;

      case 'S' :
	// nope, I cannot make sscanf work for a char then a 0 terminated string. So do a manual scan
	strncpy(out_buf, in_buf+3,  20); // hop over WS= 
	dispPrefs.begin("dispPrefs", RW_MODE);
	dispPrefs.putString("ssid",  out_buf);
	dispPrefs.end();
	load_operational_params();
	break;
	
	// end of 'W'
      }    
    }
}


/* check the serial interface to see if there are any characters, and process them if so */  

void do_serial_if_ready (void)
{
  int serial_byte;
  if (Serial.available())
    {
      serial_byte = Serial.read();
      if ((serial_byte != '\n') && (serial_buf_pointer < longest_record))
        {
          serial_buf[serial_buf_pointer] = serial_byte;  // write char to buffer if space is available
          serial_buf_pointer++;
        }    
      if (serial_byte == '\n') {
        serial_buf[serial_buf_pointer] = (uint8_t) 0;  // write string terminator to buffer
        if (serial_buf_pointer >= 1) {                 // at least a command letter
          parse_buf(serial_buf);      // parse the buffer if at least one char in it.
          // Serial.print(return_buf);
        }
        serial_buf_pointer = 0;
      }
    }
}

// I have a udp packet in. Parse the stuff I care about out of it.
void parse_udp (void)
{
  // see what type of packet it is.
  uint16_t msg_type = fetch_le_uint16(udp_msg_type_offset);
  //  Serial.printf("got msg type %x\n", msg_type);
  if (msg_type == batrium_msg_5732)
    {
      // Serial.println("got 5732");
      parse_udp_5732();
      // new_data just means a 5732 (the more frequent one) packet has arrived. I don't bother
      // to check if the data I display is actually different. This reduces display flicker to acceptable
      // to me levels.  
      new_data = true;
    }
  else
    if (msg_type == batrium_msg_3233)
      {
	parse_udp_3233();
      }
}


/* parse the variables I want from a Batrium UDP message type 5732 System Discovery Information */
void parse_udp_5732 (void)
{
  dd_data.pack_v     = fetch_le_uint16(dd_offset_5732.pack_v);
  dd_data.pack_i     = fetch_le_float(dd_offset_5732.pack_i);
  dd_data.pack_soc   = ( uint8_t )  udp_buffer[dd_offset_5732.pack_soc];
  dd_data.cell_min_v = fetch_le_uint16(dd_offset_5732.cell_min_v);
  dd_data.cell_max_v = fetch_le_uint16(dd_offset_5732.cell_max_v);
  dd_data.cell_min_t = ((uint8_t) udp_buffer[dd_offset_5732.cell_min_t] )- 40;
  //Serial.printf("packv=%d packi=%d soc=%d minv=%d, maxv=%d mint=%d\n",
  //		 dd_data.pack_v, dd_data.pack_i,
  //		 dd_data.pack_soc, dd_data.cell_min_v,
  //		 dd_data.cell_max_v, dd_data.cell_min_t);
		 
}  

/* parse the variables I want from a Batrium UDP message type 3233 System Discovery Message */
void parse_udp_3233 (void)
{
  dd_data.cell_max_t = ((uint8_t) udp_buffer[dd_offset_3233.cell_max_t]) -40;
}  

// fetch littleendian uint16 from a batrium sourced buffer carried over udp
uint16_t fetch_le_uint16 (uint8_t offset)
{
  uint16_t val;
  // batrium uses little endian buffer data arrangement 
  val = (udp_buffer[offset + 1] << 8) + udp_buffer[offset] ; 
  return val;
}


// not at all sure this works. Certainly doesn't work right when the test app is run on an intel PC.
// do note the perl caveats on float formats being device specific..
// but as I intend to use it from an ESP sourse to an ESP32 sink, its worth testing on the real thing.

// fetch littleendian 4 byte float from a batrium sourced buffer carried over udp
float fetch_le_float (uint8_t offset)
{
  // batrium uses little endian buffer data arrangement. as does esp32
  // return copyfloat;
  //  Serial.printf("saw %2x %2x %2x %2x for I float\n", udp_buffer[44],  udp_buffer[45],  udp_buffer[46],  udp_buffer[47]);
  memcpy(&copyfloat,  &udp_buffer[offset], 4);
  return copyfloat;
}

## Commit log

2025-06-19 initial commit to dedicated repo
    [dashdisplay_lcd_wiring.kicad_pcb, dashdisplay_lcd_wiring.kicad_sch, dashdisplay_motherboard.kicad_pcb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]
2025-06-20 fixed stupid float display bug affecting pack-I
    [dashdisplay.ino, parsers.ino]
2025-06-23 add a few photos
    [dd_3.FCStd, dd_front_nospigot.FCStd, dd_front_nospigot.stl]
2025-06-26 add photos of assembly and display running
    [dd_spigot.FCStd, dd_spigot.stl]
